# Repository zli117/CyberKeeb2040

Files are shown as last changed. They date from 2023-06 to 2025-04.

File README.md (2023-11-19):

# CyberKeeb 2040
A mechnical keyboard and a cyberdeck. Powered by [PicoMK](https://github.com/zli117/PicoMK) for communication between RP2040 and Pi Zero. Watch the demo on YouTube 👇.

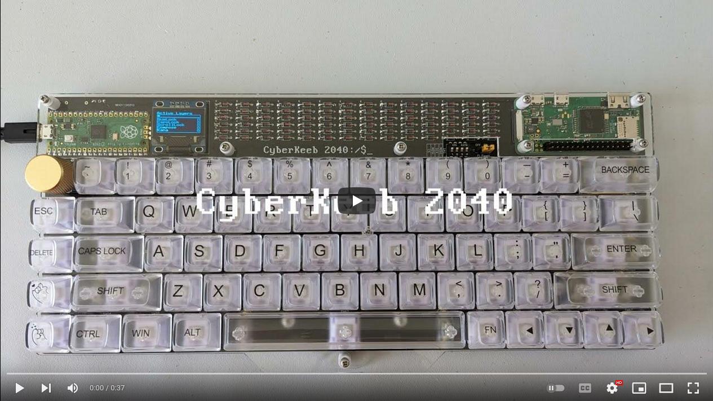
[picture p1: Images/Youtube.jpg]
Watch the demo video (https://youtu.be/GYs4eybdZCU)


# Table of Contents

- [CyberKeeb 2040](#cyberkeeb-2040)
- [Table of Contents](#table-of-contents)
- [Build](#build)
  - [PCB](#pcb)
  - [Frame](#frame)
- [Photos](#photos)
  - [V2](#v2)
  - [V1](#v1)
- [Q\&A](#qa)
- [PCB Library Licenses](#pcb-library-licenses)

# Build

[**V2 parts list and build instructions**](Docs/BuildInstructions_V2.md)

[V1 parts list and build instructions](Docs/BuildInstructions_V1.md)

## PCB
Everything is in [PCB/MainBoard](PCB/MainBoard) dir. Designed with Kicad 7.0. Make sure `Perfect DOS VGA 437 Font` is intalled on Windows, or if you use Arch, install the [ttf-perfectdos](https://aur.archlinux.org/packages/ttf-perfectdos) package. [PCB/MainBoard/Gerber](PCB/MainBoard/Gerber) dir contains the Gerber files for three fab houses: [JLCPCB](PCB/MainBoard/Gerber/JLCPCB/), [PCBWay](PCB/MainBoard/Gerber/PCBWay/), and [OSHPark](PCB/MainBoard/Gerber/OSHPark/). For JLCPCB and PCBWay, **make sure to select the Castellated Holes option** (this will increase the price, but I found it necessary for good castellated holes).

## Frame
The frame has three acrylic plates and is held together with screws and standoffs.

 * [Frame/MainBoard/TopBar.dxf](Frame/MainBoard/TopBar.dxf): 3mm acrlyic
 * [Frame/MainBoard/Plate.dxf](Frame/MainBoard/Plate.dxf): 1.5mm acrlyic
 * [Frame/MainBoard/Bottom.dxf](Frame/MainBoard/Bottom.dxf): 3mm acrlyic

# Photos

## V2

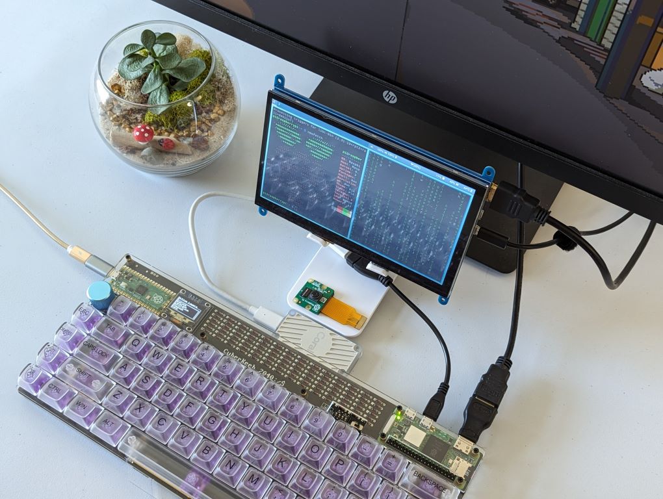
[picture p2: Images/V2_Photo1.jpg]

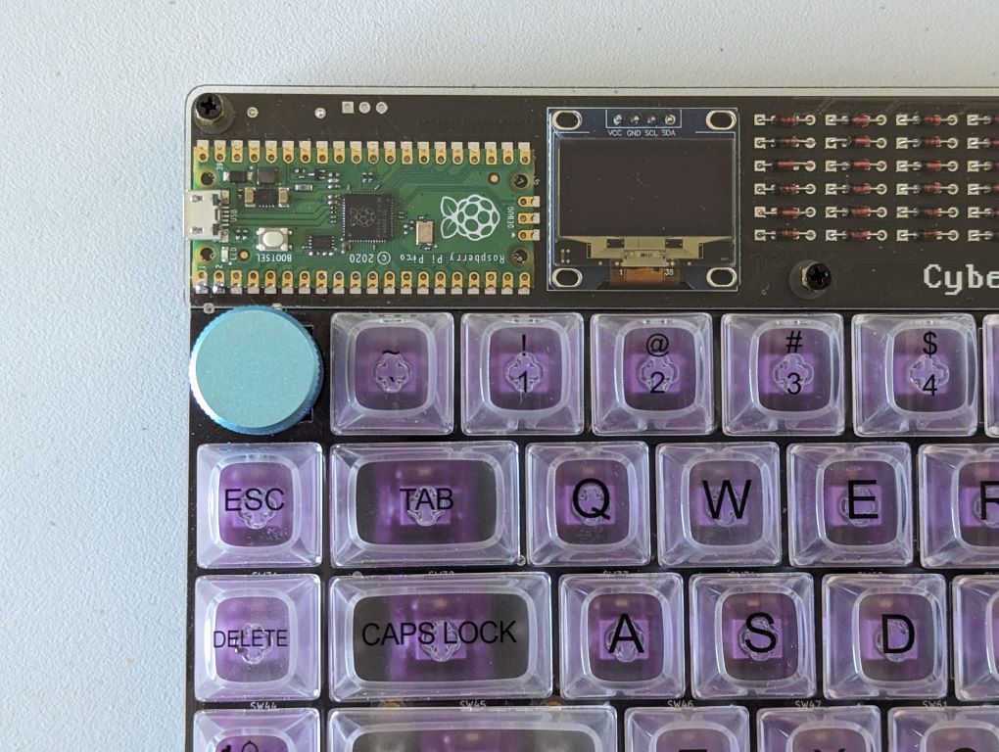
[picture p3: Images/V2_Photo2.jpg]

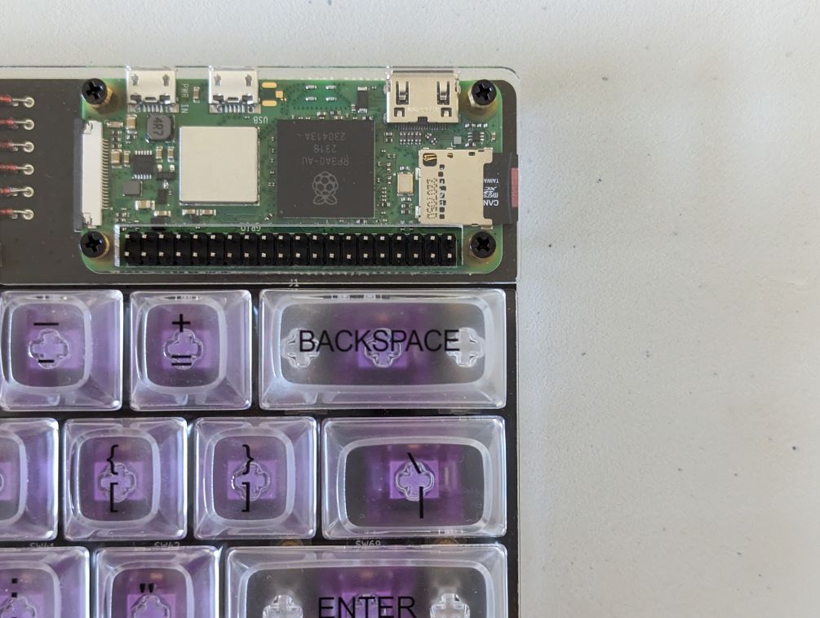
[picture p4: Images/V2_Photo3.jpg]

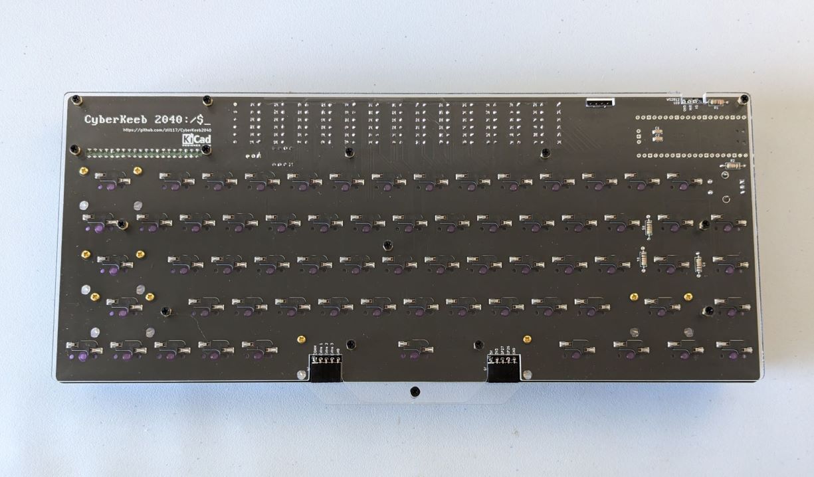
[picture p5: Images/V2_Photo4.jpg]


## V1

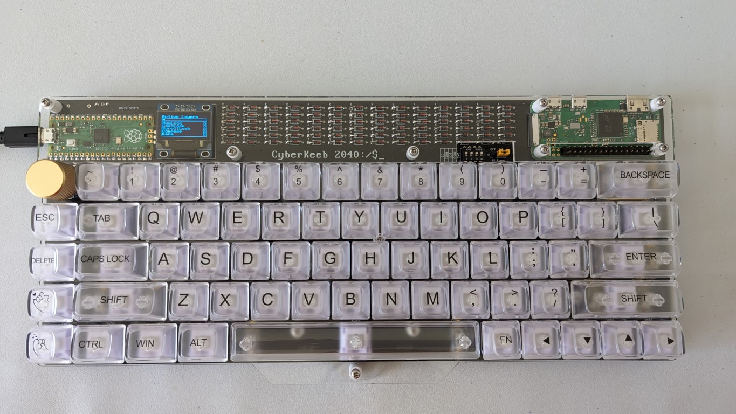
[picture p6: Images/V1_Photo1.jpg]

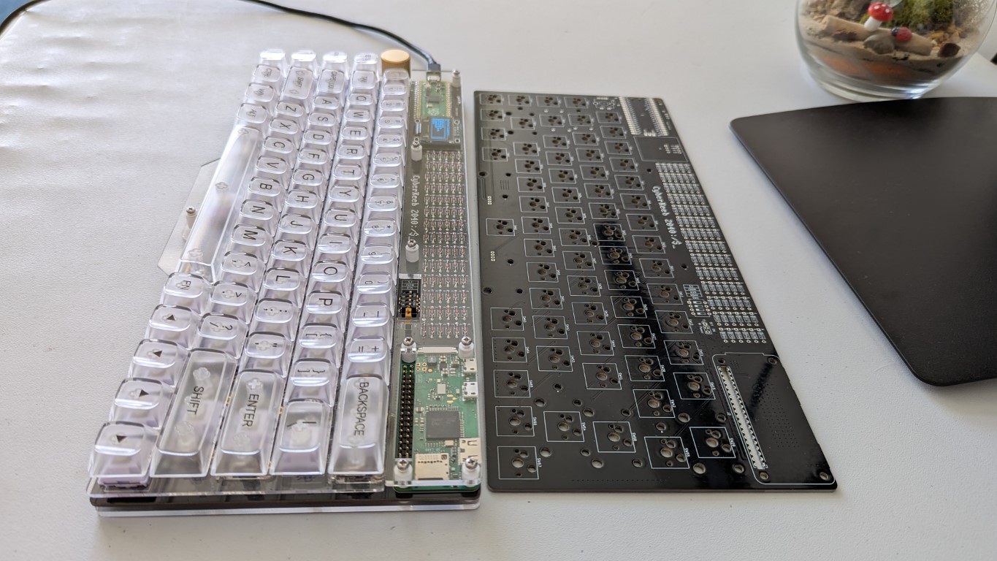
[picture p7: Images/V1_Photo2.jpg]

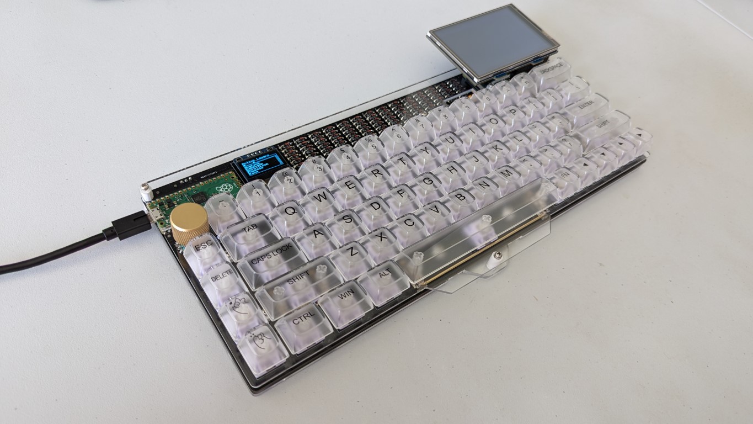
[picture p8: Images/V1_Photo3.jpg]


# Q&A

Special thanks to [icon-oclast](https://github.com/icon-oclast) for [asking](https://github.com/zli117/CyberKeeb2040/issues/2) these great questions.

> What are the dip switches used for? Is there a recommended default setting for these?

The 4 positions are for each line of the SPI connection between the pi pico and pi zero. This allows cutting the connections between pi pico and pi zero without cutting the power connections. I initially designed it for the (paranoid) scenario where I can't kill the pi zero, but doesn't want it to do autotype or receiving the key strokes, but I found such scenario increasing unlikely. So, if you don't want to solder the DIP switches, feel free to just short the corresponding pins.

> Presumably the switch/jumper labeled "pi power" controls pass-through power from the Pico to the Zero?

Yes.

> Is there a minimum USB current needed when powering both boards

I don't have the empirical measurements, but here's the estimate:
Pico: <20mA. Data source: https://mjoldfield.com/atelier/2021/11/pico-power.html
SSD1306: <7mA. Data source: https://hsel.co.uk/2018/12/04/ssd1306-power-consumption/
Pi Zero W: <400mA under stress. Data source: https://www.tomshardware.com/reviews/raspberry-pi-zero-2-w-review
Pi Zero 2 W: <600mA under stress.

So let's say it's 700mA if you want to stress the pi zero. I did run the stressberry on pi zero 2 w, with the display hat, and a wireless mouse receiver. The board is connected to the USB3.0 port and there's no under voltage warning, and no visible heat up on the cable or the connectors. However, due to differences on the motherboards, YMMY. I currently don't have a USB power meter to measure the actual current drawn.

> Is there a maximum safe current to pass-through (when using the optional display hat for example)?

The trace between pico and pi zero has width of 1mm, and length around 300mm. Assuming you're using 1oz copper thickness, it should result in a maximum current of 1.2 A for temperature rise of 10 degree C.

> Is it safe to power the zero independently by setting the pi power switch/jumper to off?

Yes.

> What about the two connectors at the bottom of the board, either 4-pin jst sockets as in the build instructions, or possibly 5-pin headers on some revisions of the pcb, how are they intended to be used?

They are for my future plans :) Essentially, they expose three buttons from the key scan matrix, and pin 26 and 27. Pin 26 and 27 are analog input pins and I2C 1. I'm planning to create a plugin module for the joystick mouse pad similar to the one I have on the Pico-Keyboard, and an I2C expansion board for more modules like a num pad. 

> What cool things can we do if we include the optional 90 degree pin header(s)?

The pin header under the small screen has been removed, because I figured it'll be difficult to use it for anything without creating a giant mess in the firmware. The other header exposes the addressable LEDs. Only WS2812 is supported and tested because it's used in the Pico-Keyboard. However, you might be able to use for other things as it's essentially a GPIO pin with ground and 5V, and a 330 ohm resister on the GPIO pin.

# PCB Library Licenses

 * Pico symbol, footprint from https://github.com/ncarandini/KiCad-RP-Pico under CC-BY-SA 4.0. 3D model for Pico is obtained from Raspberry Pi Foundation.
 * Pi Zero symbol, footprint and 3D model are from [SnapEDA](https://www.snapeda.com/parts/ADA3708/Adafruit%20Industries%20LLC/view-part/) under [CC BY-SA 4.0](https://support.snapeda.com/en/articles/2957814-what-is-the-license-for-symbols-and-footprints)
 * Key switch footprints and 3D models are from https://github.com/kiswitch/kiswitch
 * PJ320A symbol, footprint are from [Keebio-Parts.pretty](https://github.com/keebio/Keebio-Parts.pretty/blob/master/TRRS-PJ-320A.kicad_mod) under MIT License.
 * Other symbols are from KiCad library which is under CC-BY-SA 4.0 license. 

This work is licensed under a
[Creative Commons Attribution-ShareAlike 4.0 International License][cc-by-sa].

[][cc-by-sa]

[cc-by-sa]: http://creativecommons.org/licenses/by-sa/4.0/
[cc-by-sa-image]: https://licensebuttons.net/l/by-sa/4.0/88x31.png
[cc-by-sa-shield]: https://img.shields.io/badge/License-CC%20BY--SA%204.0-lightgrey.svg

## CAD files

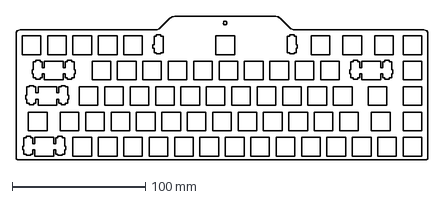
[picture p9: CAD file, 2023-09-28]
Frame/MainBoard/Plate.dxf
308.8 x 107.3 mm

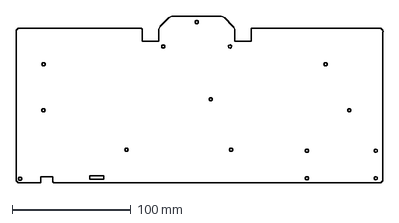
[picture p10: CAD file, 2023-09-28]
Frame/MainBoard/Bottom.dxf
308.8 x 140.3 mm

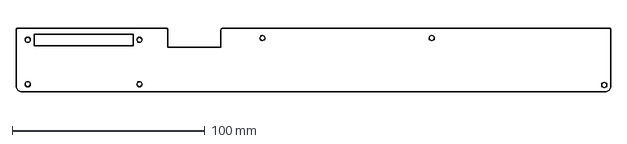
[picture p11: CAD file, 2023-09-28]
Frame/MainBoard/TopBar.dxf
308.8 x 33.0 mm

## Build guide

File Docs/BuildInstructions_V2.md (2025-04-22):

# V2 Build Instructions

## Necessary Parts

| Image | Part Name | Count |
| --- | --- | ----- |
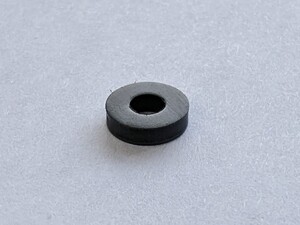
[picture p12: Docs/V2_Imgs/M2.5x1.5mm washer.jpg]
|  | M2.5x1.5mm washer | 3 |
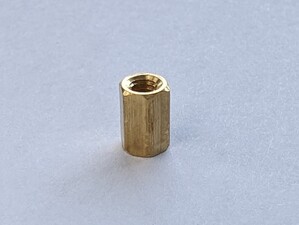
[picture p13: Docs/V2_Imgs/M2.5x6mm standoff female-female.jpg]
|   | M2.5x6mm standoff female-female  | 7 |
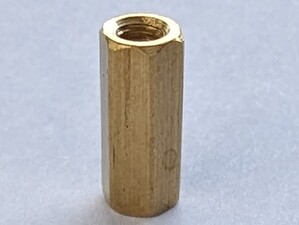
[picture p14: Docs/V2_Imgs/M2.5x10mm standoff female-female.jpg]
|  | M2.5x10mm standoff female-female | 1 |
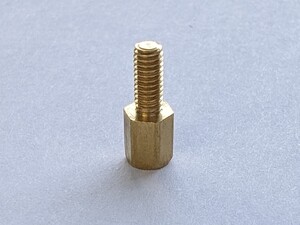
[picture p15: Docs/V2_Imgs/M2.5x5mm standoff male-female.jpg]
|  | M2.5x5mm standoff male-female | 7 |
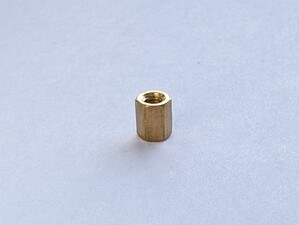
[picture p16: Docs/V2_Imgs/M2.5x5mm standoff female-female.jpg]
|   | M2.5x5mm standoff female-female  | 7 |
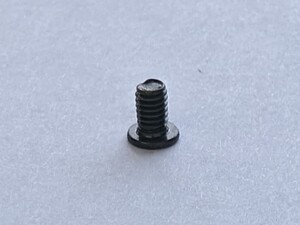
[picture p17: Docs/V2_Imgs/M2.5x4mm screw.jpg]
|  | M2.5x4mm screw | 8 |
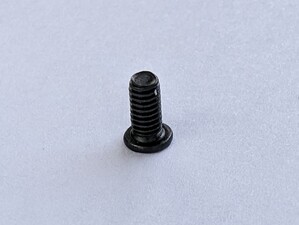
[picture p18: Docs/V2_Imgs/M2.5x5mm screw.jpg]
|  | M2.5x5mm screw | 22 |
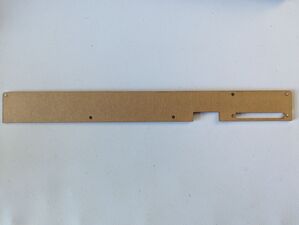
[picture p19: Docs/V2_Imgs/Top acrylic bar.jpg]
|  | Top acrylic bar | 1 |
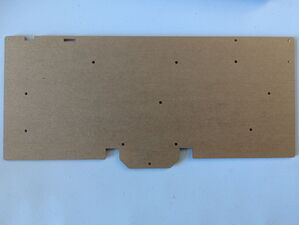
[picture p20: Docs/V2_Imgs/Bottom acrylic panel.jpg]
|  | Bottom acrylic panel | 1 |
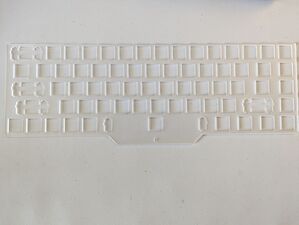
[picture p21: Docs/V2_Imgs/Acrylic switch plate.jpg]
|  | Acrylic switch plate | 1 |
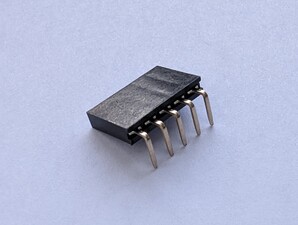
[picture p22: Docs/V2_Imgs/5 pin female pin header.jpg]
|  | 5 pin female pin header | 2 |
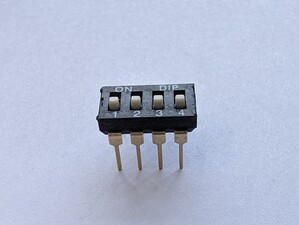
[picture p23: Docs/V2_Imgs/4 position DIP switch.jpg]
|  | 4 position DIP switch | 1 |
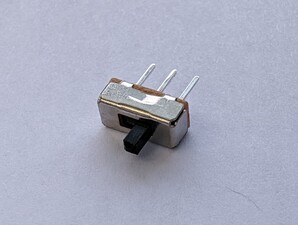
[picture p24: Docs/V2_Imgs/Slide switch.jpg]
|  | Slide switch | 1 |
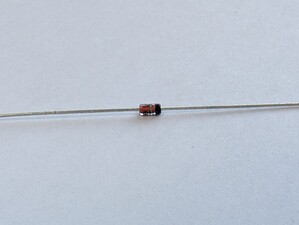
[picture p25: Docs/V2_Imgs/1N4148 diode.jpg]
|  | 1N4148 diode | 84 |
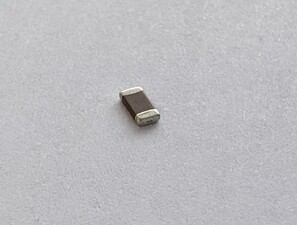
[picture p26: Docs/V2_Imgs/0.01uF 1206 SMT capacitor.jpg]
|  | 0.01uF 1206 SMT capacitor | 2 |
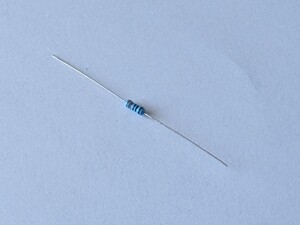
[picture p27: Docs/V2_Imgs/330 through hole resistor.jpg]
|  | 330Ω through hole resistor | 1 |
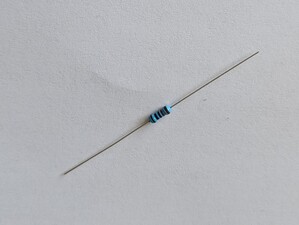
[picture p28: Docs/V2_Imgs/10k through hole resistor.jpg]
|  | 10kΩ through hole resistor | 4 |
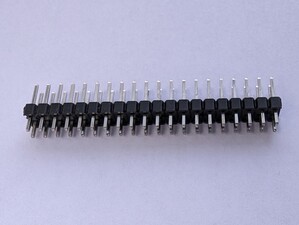
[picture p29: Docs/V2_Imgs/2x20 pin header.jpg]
|  | 2x20 pin header | 1 |
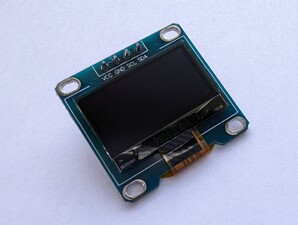
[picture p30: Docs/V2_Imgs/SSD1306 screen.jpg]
|  | SSD1306 screen | 1 |
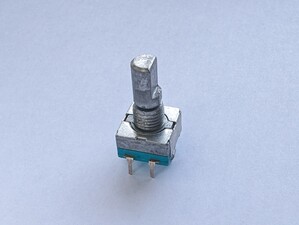
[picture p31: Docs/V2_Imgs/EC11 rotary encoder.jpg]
|  | EC11 rotary encoder | 1 |
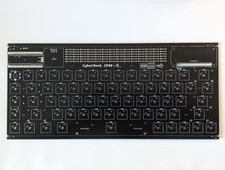
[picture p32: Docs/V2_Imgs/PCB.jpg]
|  | PCB | 1 |
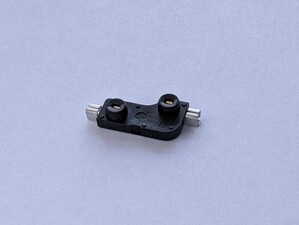
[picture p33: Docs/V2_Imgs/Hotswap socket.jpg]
|  | Hotswap socket | 66 |
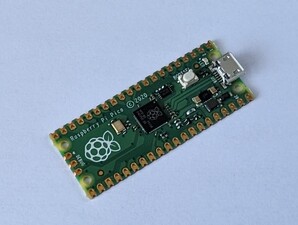
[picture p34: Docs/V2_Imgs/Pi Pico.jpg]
|  | Pi Pico | 1 |
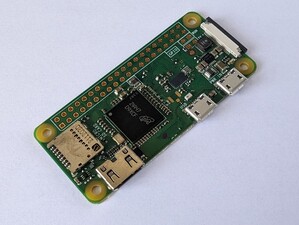
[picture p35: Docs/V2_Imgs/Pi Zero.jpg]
|  | Pi Zero / Zero 2 | 1 |

## You Also Need

- Soldering iron. Conical tip is recommended.
- Solder wire. Thin solder wire with less than 0.03 inch diameter is recommended.
- Tweezer.
- Wire cutter to remove diode pins.
- Tape or hot glue gun.
- Key switches.
- Key caps.
- Stablizers.

## PCB Assembly

### Recommended Assembly Order

1. Diodes
2. Hotswap sockets
3. Resisters
4. Capacitors
5. Pi Pico
6. 5 pin female header + DIP swtich + slide switch
7. Rotary encoder
8. Pi Zero + 2x20 pin header

### Solder Pi Zero 

1. Secure Pi Zero to the PCB using two pairs of male-female and female-female standoffs, as such:

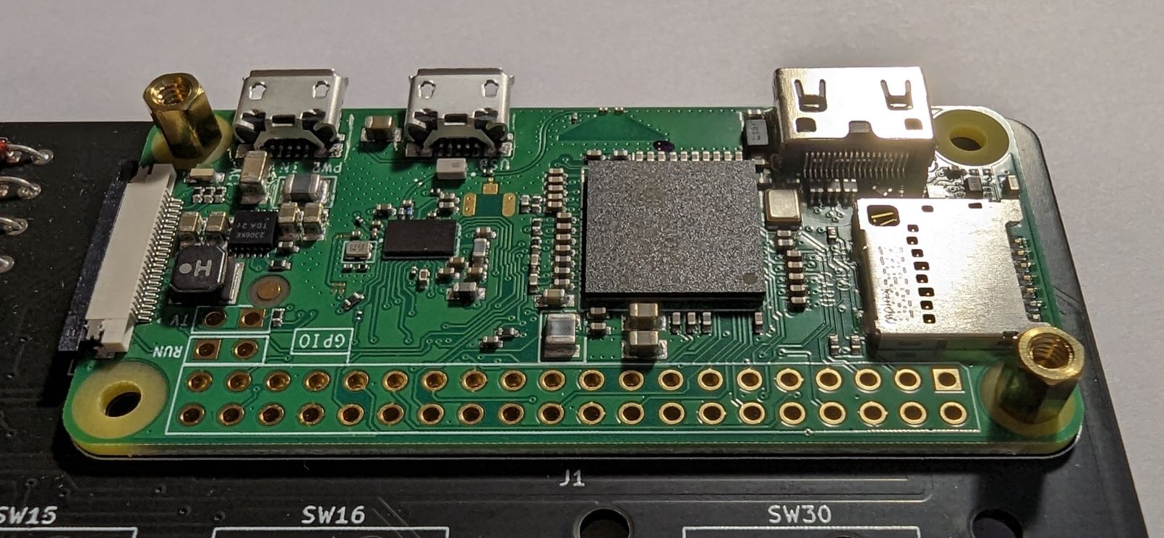
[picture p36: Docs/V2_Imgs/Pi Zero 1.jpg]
Pi Zero Screw Down
   
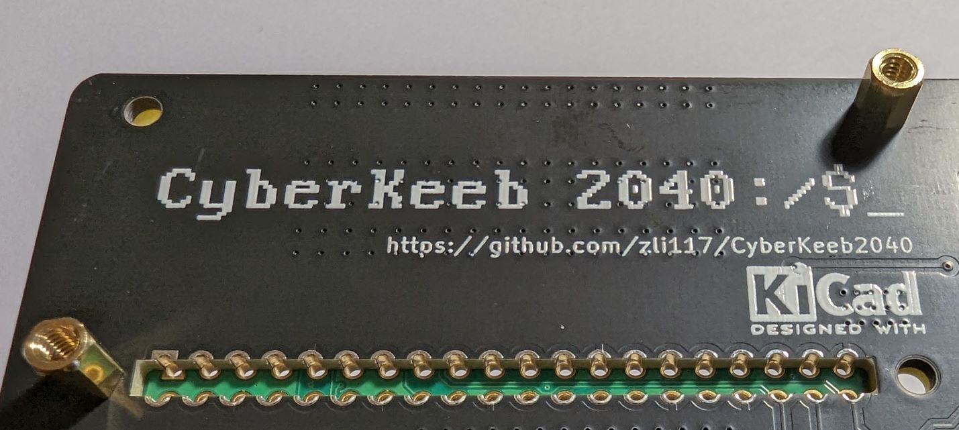
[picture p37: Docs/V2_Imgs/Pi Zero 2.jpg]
Pi Zero Screw Down
   

2. Tape down the pin header

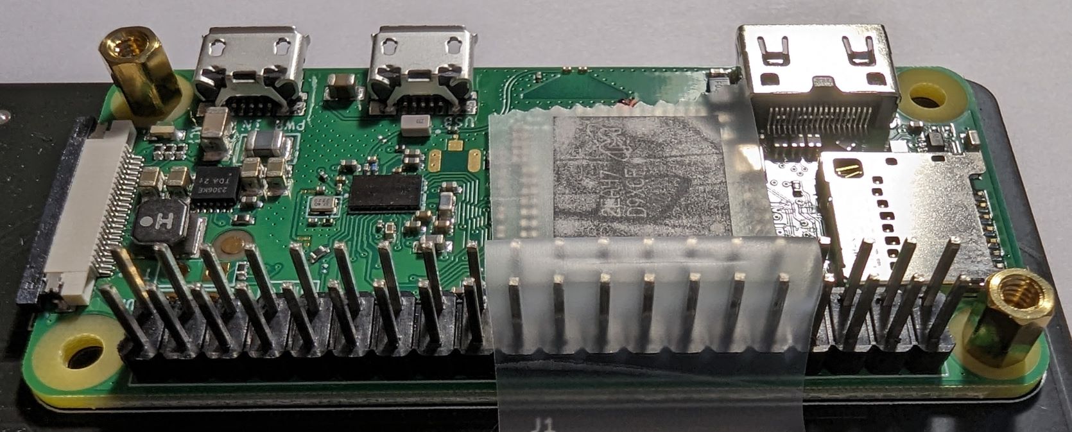
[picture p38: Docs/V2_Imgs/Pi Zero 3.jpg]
Pi Zero Header Tape
   

   You can also use hot glue. Just be careful not to cover the small components on Pi Zero. Remove the tape when soldering the pins it covers. The pins can conduct the heat and melt the tape.

3. Solder the pin with the keyboard PCB and the Pi Zero:

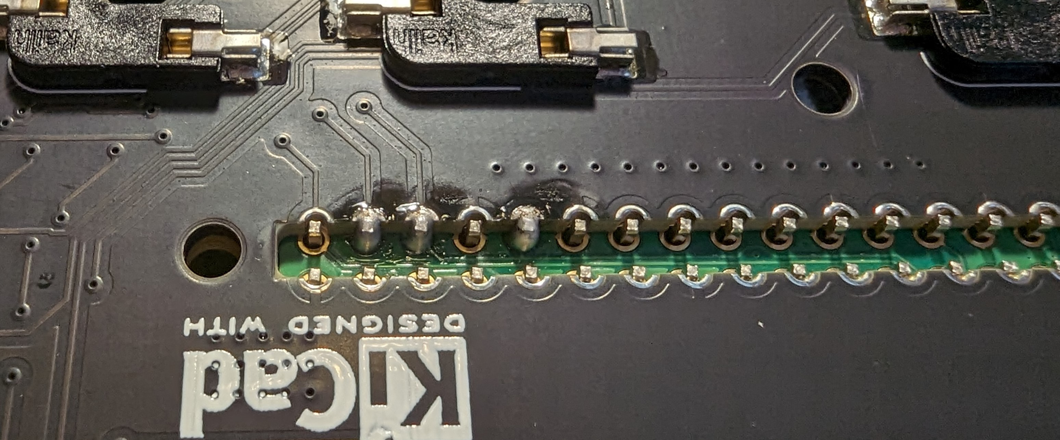
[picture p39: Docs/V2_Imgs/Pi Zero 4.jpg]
Pi Zero Solder
   

   Bring in the soldering iron vertically, and press the tip againt the pin, the keyboard PCB and the Pi Zero PCB. Hold for half a second to a second to heat up the pads. Then feed in the solder wire from the left, touching the pin and the pads:

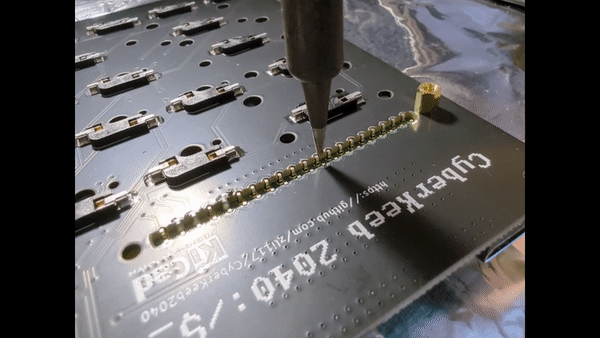
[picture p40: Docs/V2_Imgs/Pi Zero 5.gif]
Pi Zero Solder gif
   

   Tip: use thin solder wire with less than 0.03 inch diameter. 

4. Remove the standoffs. 

### Solder the Diodes

Make sure the cathode band is aligned with the square pad:

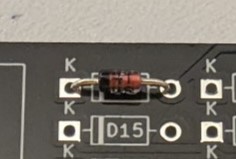
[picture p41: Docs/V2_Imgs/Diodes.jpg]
Diodes


### Solder Hotswap Sockets

1. Tin one of the pads:

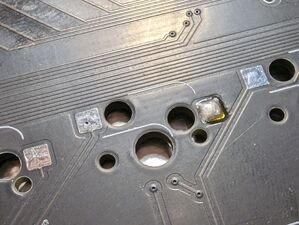
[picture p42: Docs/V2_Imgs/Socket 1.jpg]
Socket 1
   

2. Place the socket, and solder the tinned pin:

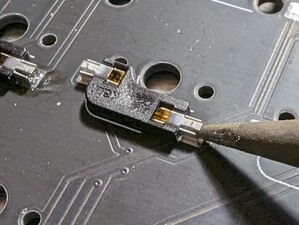
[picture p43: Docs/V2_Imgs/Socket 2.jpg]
Socket 2
   

   Place the tip of the soldering iron as shown and press down. You might also want to use a tweezer to press down on the other pin.

3. Solder the other pin.

### Solder the SMD Capacitors

The process is similar to the hotswap socket. Capacitor doesn't have any polarity.

1. Tin one of the pads.
2. Use the tip of the soldering iron to melt the tin, and slide in the capacitor.
3. Solder the other end.

This [video](https://www.youtube.com/watch?v=_DsCdOaRUPM) is a nice demonstrateion.

## Frame Assembly

### Step 1
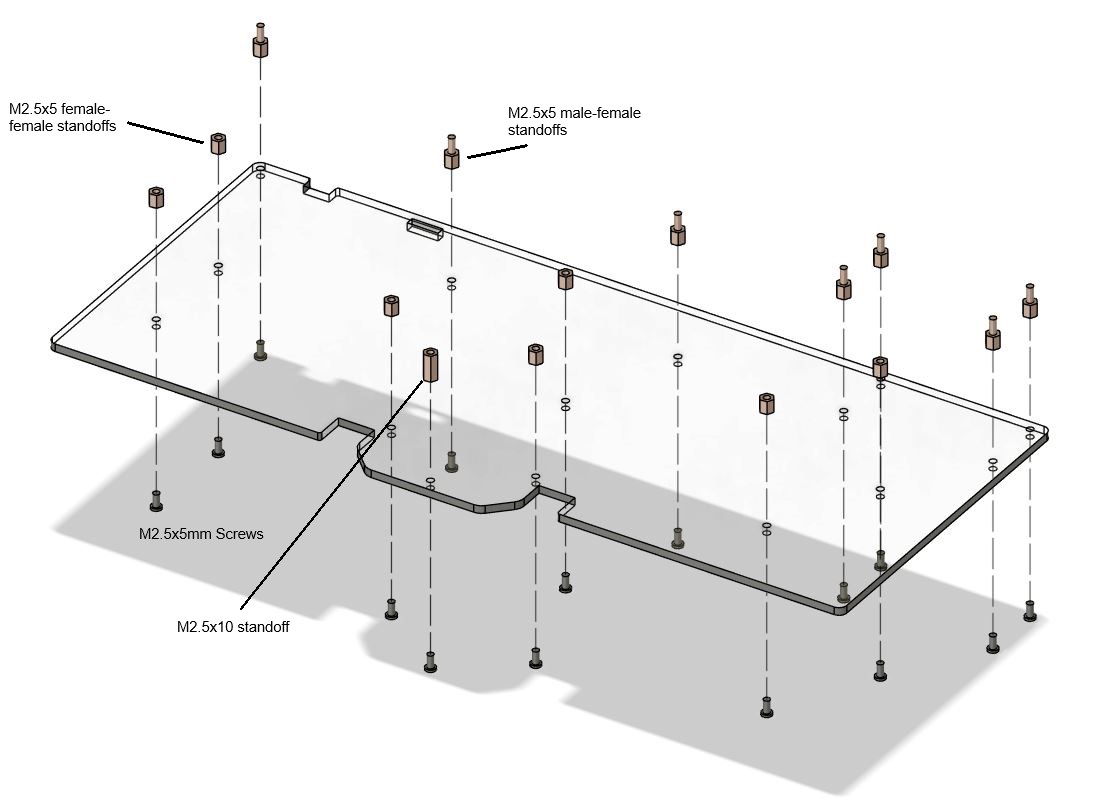
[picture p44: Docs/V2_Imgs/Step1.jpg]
Step 1


Install the standoffs to the bottom panel. All the screws used here are M2.5x5mm. There are 7 M2.5x5 male-female standoffs for the top part of the panel, and 7 M2.5x5 female-female standoffs for the lower part. There's 1 M2.5x10mm standoff at the very bottom.

### Step 2
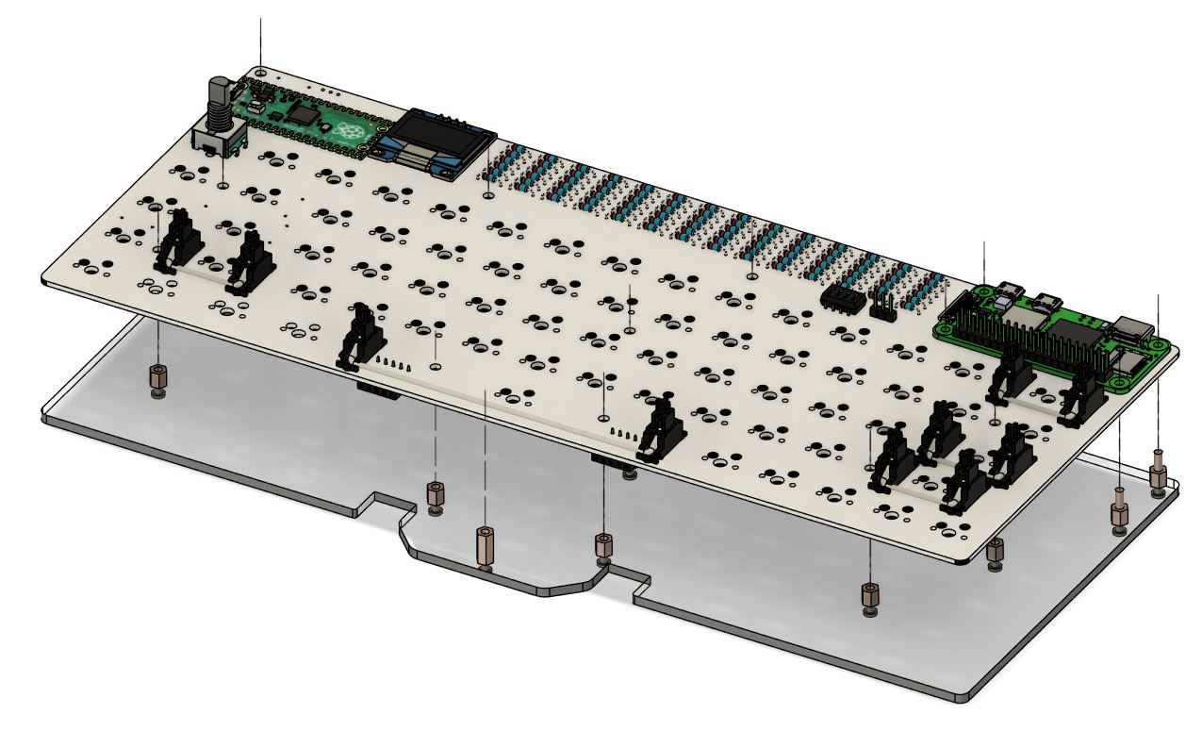
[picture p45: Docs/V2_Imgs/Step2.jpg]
Step 2


Align the PCB to the standoffs.

### Step 3
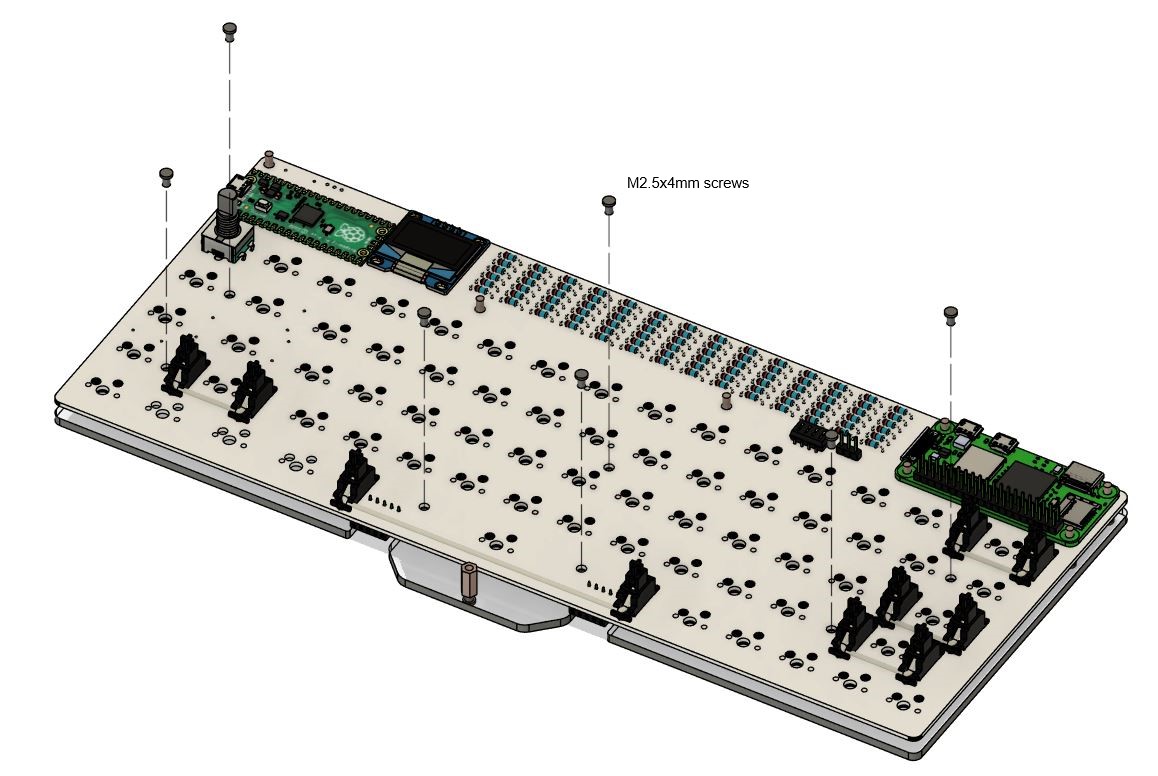
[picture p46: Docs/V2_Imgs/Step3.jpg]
Step 3


Screw down the PCB with 7 M2.5x4mm screws.

### Step 4
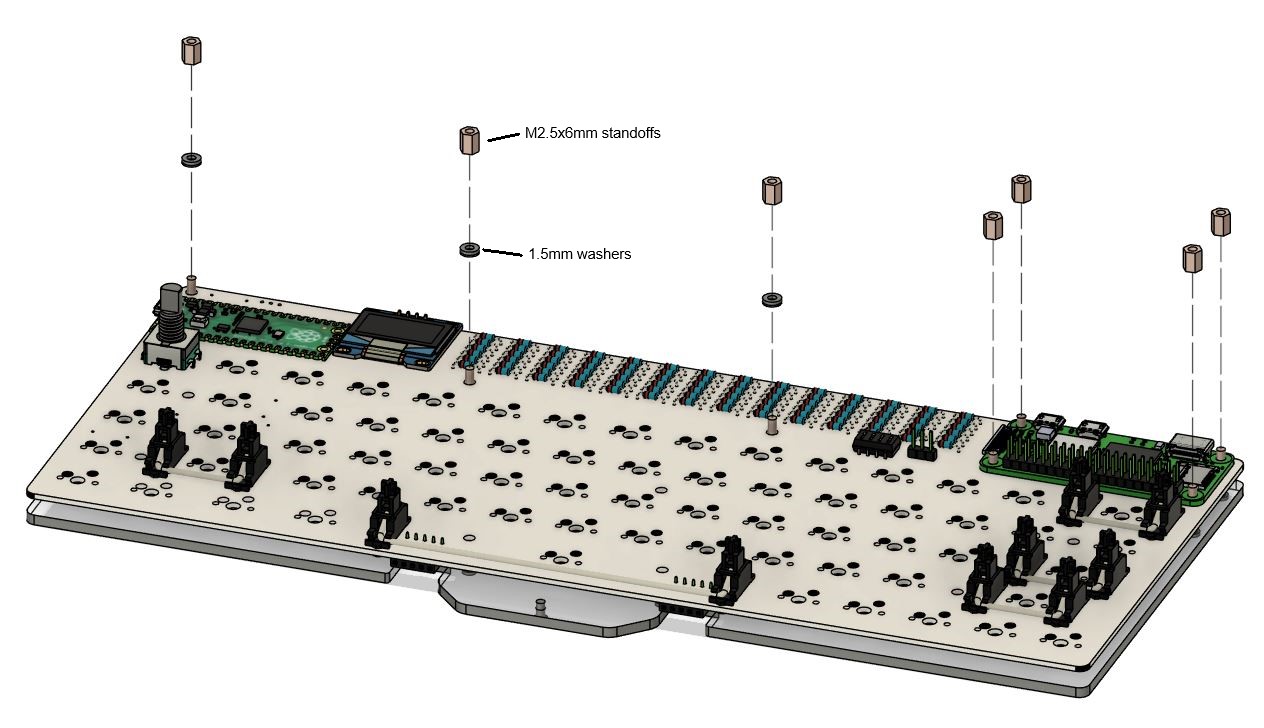
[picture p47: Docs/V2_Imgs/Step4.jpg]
Step 4


Install the top bar standoffs with 7 M2.5x6mm standoffs. For the ones not over the Pi Zero, add a 1.5mm washer.

### Step 5
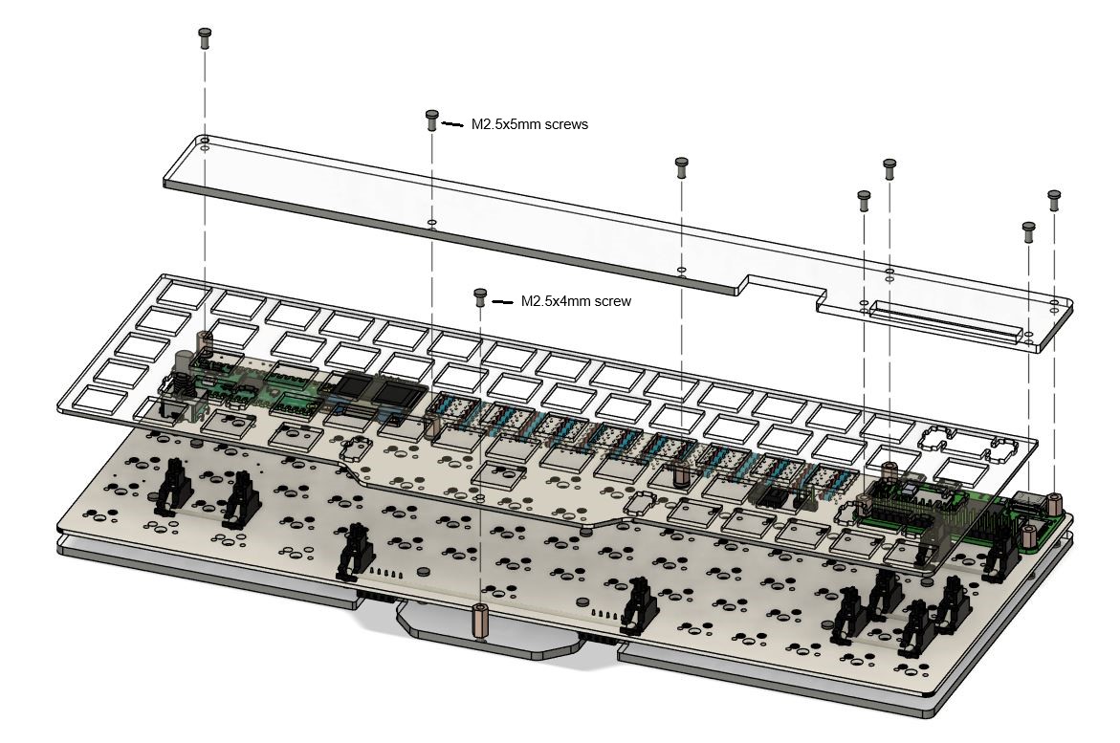
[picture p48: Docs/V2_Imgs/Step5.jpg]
Step 5


Install the top bar and the plate. 

Tip: Add the switches, at least the ones on the edge, to the plate before installing the plate.

## Build Software

### Pi Pico Firmware

Install build dependencies:

Arch Linux:
```bash
pacman -S git cmake arm-none-eabi-gcc arm-none-eabi-newlib
```

For other distros or OS, see https://github.com/zli117/PicoMK#get-the-code

Check out the code:
```bash
git clone https://github.com/zli117/PicoMK.git
cd PicoMK
git submodule update --init && git -C pico-sdk submodule update --init
```

The hardware configuration for this keyboard is defined in `configs/cyberkeeb_2040` dir in `PicoMK`. You can take a look at the [`layout.cc`](https://github.com/zli117/PicoMK/blob/main/configs/cyberkeeb_2040/layout.cc) for the details on the keymap.

Build the firmware:

```bash
mkdir build
cd build
cmake -DBOARD_CONFIG=cyberkeeb_2040 ..
make -j 4
```

If successful, you can find the `firmware.uf2` file in the build dir. Now, hold down the flash button on the Pico and plug it in. It will show up as a USB drive. Just copy the `firmware.uf2` file to the drive.

### Pi Zero Kernel Module

To send the keycodes to the Pi Zero, a kernel module is needed on the Pi Zero side, as it uses a custom [protocol](https://github.com/zli117/PicoMK/blob/main/docs/ibp.md) defined over SPI.

For this you'll need an external keyboard. 

1. Install kernel headers: `sudo apt install raspberrypi-kernel-headers`
2. Checkout PicoMK `git clone https://github.com/zli117/PicoMK.git`.
3. Build the driver and device tree overlay:
```bash
cd PicoMK/linux
make -j
make device_tree
```
4. Install the driver:
```bash
sudo -E make install
sudo depmod -a
```
5. Copy over the device tree overlay: `sudo cp spi1-picomk.dtbo /boot/overlays`.
6. Add this line to the `/boot/config.txt`. Make sure SPI1 is not enabled.
```
dtoverlay=spi1-picomk
```
7. Add this line to the `/etc/modules` file:
```
spi_picomk
```

If you update the Raspberry Pi OS, especially with kernel updates, you'll need to rebuild the kernel module (rerun step 4).

If you want to use the 3.5 inch GPIO TFT screen, and you're on Pi Zero, install the driver from https://github.com/juj/fbcp-ili9341. If you're on Pi Zero 2, install the driver from https://github.com/goodtft/LCD-show.

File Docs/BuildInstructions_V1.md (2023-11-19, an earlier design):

# V1 Build Instructions

## BOM
| Component | Count |
| --- | --- |
| Pi Pico  | 1 |
| Pi Zero W or Pi Zero 2 W  | 1 |
| Pi Zero 2x20 Header Pins  | 1 |
| SD Card  | 1 |
| JMD0.96C OLED Display | 1 |
| 4 Position DIP Switch | 1 |
| 0.1" 3 Pin Header + Jumper / 0.1" Pitch SPDT Slide Switch | 1 |
| Hotswap Socket | 66 |
| Keyboard Switch (Hippo Linear) | 66 |
| Keycaps (Redragon Crystal Keycap) | 66 |
| EC11 Rotary Encoder | 1 |
| Encoder Knob (Glorious) | 1 |
| 1N4148 Diode | 84 |
| M2.6 x 10mm Self Tapping Screws | 8 |
| M2.6 x 16mm Self Tapping Screws | 7 |
| 3mm Acrylic Sheet | 2 |
| 1.5mm Acrylic Sheet | 1 |
| 3D Printed Rivet + Spacers | 15 |
| JST-PH 2.0mm 4 Pin Female Connector | 2 |
| Stablizer Set | 1 |
| 330Ω THT Resister | 1 |
| 10kΩ THT Resister | 4 |
| 1206 0.01 µF Capacitor | 2 |
| (Optional) 3.5 inch TFT Display HAT | 1 |
| (Optional) 0.1" 3 Pin 90° Header | 1 |
| (Optional) 0.1" 4 Pin 90° Header | 1 |

## PCB
Everything is in [PCB/MainBoard](PCB/MainBoard) dir. Designed with Kicad 7.0. Make sure `Perfect DOS VGA 437 Font` is intalled on Windows, or if you use Arch, install the [ttf-perfectdos](https://aur.archlinux.org/packages/ttf-perfectdos) package. [PCB/MainBoard/Gerber](PCB/MainBoard/Gerber) dir contains the Gerber files for three fab houses: [JLCPCB](PCB/MainBoard/Gerber/JLCPCB/), [PCBWay](PCB/MainBoard/Gerber/PCBWay/), and [OSHPark](PCB/MainBoard/Gerber/OSHPark/). For JLCPCB and PCBWay, **make sure to select the Castellated Holes option** (this will increase the price, but it's better to be safe on the quality side).

## Case
The case comprises three acrylic plates and various 3D printed rivets. The original Fusion 360 archive is `Frame/MainBoard/CyberKeep 2040 V2 v34.f3d`. The spacer heights are parameterized.

 * [Frame/MainBoard/TopBar.dxf](Frame/MainBoard/TopBar.dxf): 3mm acrlyic
 * [Frame/MainBoard/Plate.dxf](Frame/MainBoard/Plate.dxf): 1.5mm acrlyic
 * [Frame/MainBoard/Bottom.dxf](Frame/MainBoard/Bottom.dxf): 3mm acrlyic

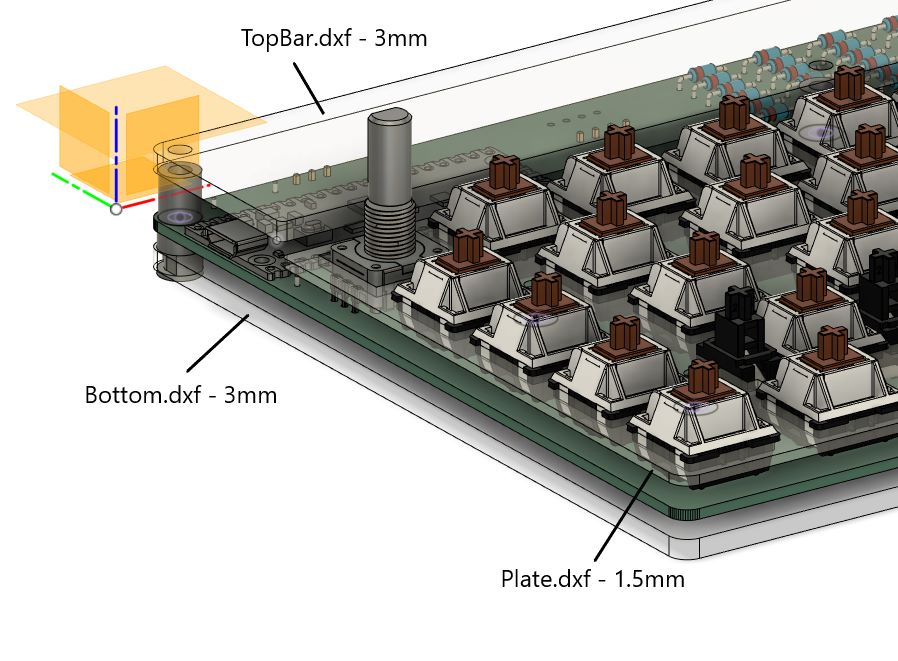
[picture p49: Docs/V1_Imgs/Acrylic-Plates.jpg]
Plates Image


The case is held together with 3D printed rivets and spacers.

### Step 1: Assemble the rivets and bottom spacers
Place the rivets through the holes on the bottom place. Then fit the spacer rings.
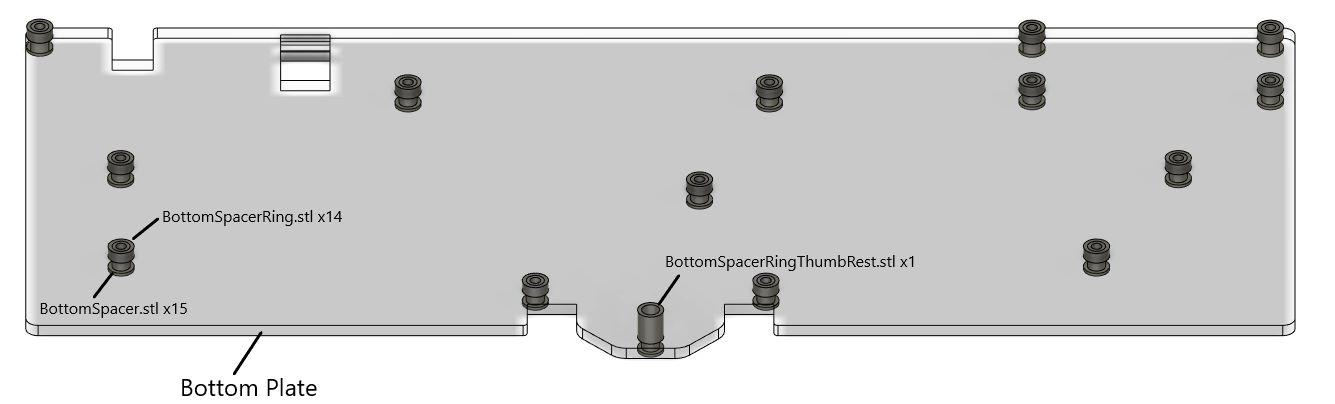
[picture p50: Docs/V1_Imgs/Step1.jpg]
Step 1


### Step 2: Place the top spacers
Place the PCB on top of the bottom spacers. Then place the top spacers as shown.
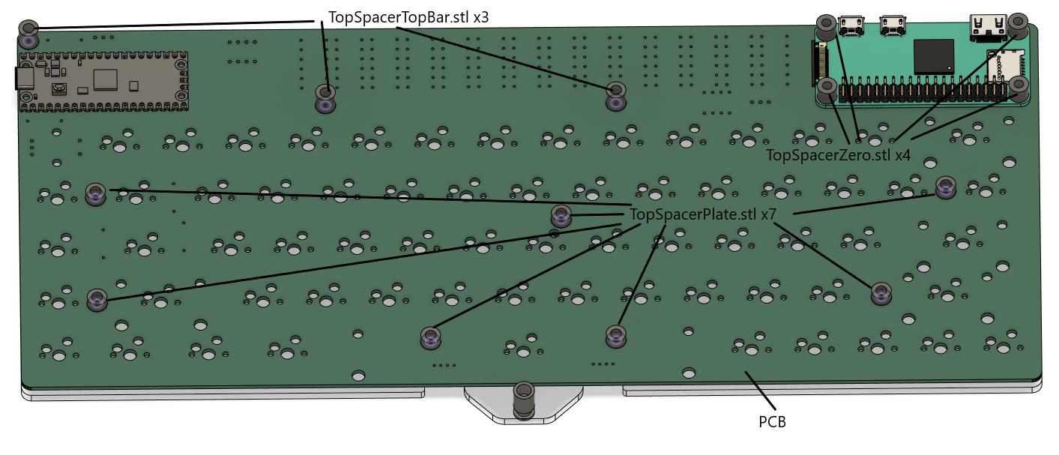
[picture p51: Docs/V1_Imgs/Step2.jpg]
Step 2


### Step 3: Secure the top plates with screws
Place the top bar acrylic plate and the switch plate on top of the top spacers. Then secure the whole assembly with screws. Use M2.6x16mm screws for the top plate, and M2.6x10mm screws for the switch plate.
Step 3

## Soldering

### Pi Zero
Soldering of Pi Zero is the trickiest. You need to solder the pins simultaneously to the keyboard PCB and the Pi Zero, via the castellated hole on the PCB. 

Zero_Bottom

This is viewed from the bottom, at the castellated hole. The green PCB is Pi Zero. Solder joint should form between the copper on the keyboard PCB, the plates on Pi Zero PCB and the pin. To make things easier, it's recommended to tape down the Pi Zero and headers:

Zero_Top

It's also recommended to solder all the pins for structural strength.

### Diodes
Align the dark side of the diode with the square pad.

Diodes

### JST Connector
Install the JST connectors on the back of the PCB. You can either solder on the back side or on the front. If on the front, tape down the connectors first.

JST

### JMD0.96C OLED Display (Marked as J4 on the front of the PCB)

If J3 is installed on the back of the PCB, place a tape on the back of the display to avoid shorting.

## Software

Keyboard firmware: https://github.com/zli117/PicoMK/tree/main/configs/cyberkeeb_2040. Follow PicoMK's [instruction](https://github.com/zli117/PicoMK/tree/main#build-a-firmware) to build the firmware and upload it to Pico microcontroller.

Linux driver for accepting key strokes from SPI: (You'll need an external screen and an external keyboard for this setup)
 1. Install kernel headers: `sudo apt install raspberrypi-kernel-headers` 
 2. Checkout PicoMK: `git clone https://github.com/zli117/PicoMK.git`
 3. Build the driver and device tree overlay:
    ```bash
    cd PicoMK/linux
    make -j
    make device_tree
    ```
 4. Install the driver: 
    ```bash
    sudo -E make install
    sudo depmod -a
    ```
 5. Copy over the device tree overlay: `sudo cp spi1-picomk.dtbo /boot/overlays`
 6. Add this line to the `config.txt`. Make sure SPI1 is not enabled. 
    ```
    dtoverlay=spi1-picomk
    ``` 
 7. Add this line to the `/etc/modules` file:
    ```
    spi_picomk
    ```

 If you're using the 3.5 inch TFT screen, you can install the driver from https://github.com/juj/fbcp-ili9341.

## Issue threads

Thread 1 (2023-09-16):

Missing Gerber directory

icon-oclast, 2023-09-16:
The Build Instructions in the ReadMe file mention a directory PCB/MainBoard/Gerber which doesn't exist in the repo HEAD.
Clicking the link gives a 404 response.

It appears the Gerber directory did exist up until the cleanup commit on Sep 6th.
It would be useful to have these restored, or alternately If removing these from the repo entirely was the intent, then the ReadMe should be updated.

zli117, 2023-09-16:
Thanks for the reminder! I removed the Gerber files as I'm doing some final tweaks on the PCB design. Will update once the new design is verified. I'm currently waiting for the new boards to arrive.

icon-oclast, 2023-10-08:
I see the latest update once again has Gerber files.
Thank you!

Closed 2023-10-08.

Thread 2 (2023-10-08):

operating details

icon-oclast, 2023-10-08:
This keyboard has some very unique features not found in any other keyboard.
Unfortunately there appears to be little information regarding these beyond the build instructions.  Some of these may benefit from some additional detail.  For example:
  * What are the dip switches used for?  Is there a recommended default setting for these?
  * Presumably the switch/jumper labeled "pi power" controls pass-through power from the Pico to the Zero?  Is there a minimum USB  current needed when powering both boards?  Is there a maximum safe current to pass-through (when using the optional display hat for example)?  Is it safe to power the zero independently by setting the pi power switch/jumper to off?
  * What about the two connectors at the bottom of the board, either 4-pin jst sockets as in the build instructions, or possibly 5-pin headers on some revisions of the pcb, how are they intended to be used?
  * What cool things can we do if we include the optional 90 degree pin header(s)?

Any details or suggestions are greatly appreciated!

zli117, 2023-10-08:
Hello icon-oclast, thanks for the questions. Here are the responses:

> What are the dip switches used for? Is there a recommended default setting for these?

The 4 positions are for each line of the SPI connection between the pi pico and pi zero. This allows cutting the connections between pi pico and pi zero without cutting the power connections. I initially designed it for the (paranoid) scenario where I can't kill the pi zero, but doesn't want it to do autotype or receiving the key strokes, but I found such scenario increasing unlikely. So, if you don't want to solder the DIP switches, feel free to just short the corresponding pins

> Presumably the switch/jumper labeled "pi power" controls pass-through power from the Pico to the Zero?

Yes

>  Is there a minimum USB current needed when powering both boards

I don't have the empirical measurements, but here's the estimate:
Pico: <20mA. Data source: https://mjoldfield.com/atelier/2021/11/pico-power.html
SSD1306: <7mA. Data source: https://hsel.co.uk/2018/12/04/ssd1306-power-consumption/
Pi Zero W: <400mA under stress. Data source: https://www.tomshardware.com/reviews/raspberry-pi-zero-2-w-review
Pi Zero 2 W: <600mA under stress.

So let's say it's 700mA if you want to stress the pi zero. I did run the stressberry on pi zero 2 w, with the display hat, and a wireless mouse receiver. The board is connected to the USB3.0 port and there's no under voltage warning, and no visible heat up on the cable or the connectors. However, due to differences on the motherboards, YMMY. I currently don't have a USB power meter to measure the actual current drawn.

> Is there a maximum safe current to pass-through (when using the optional display hat for example)?

The trace between pico and pi zero has width of 1mm, and length around 300mm. Assuming you're using 1oz copper thickness, it should result in a maximum current of 1.2 A for temperature rise of 10 degree C.

> Is it safe to power the zero independently by setting the pi power switch/jumper to off?

Yes.

> What about the two connectors at the bottom of the board, either 4-pin jst sockets as in the build instructions, or possibly 5-pin headers on some revisions of the pcb, how are they intended to be used?

They are for my future plans :) Essentially, they expose three buttons from the key scan matrix, and pin 26 and 27. Pin 26 and 27 are analog input pins as well as I2C 1. I'm planning to create a plugin module for the joystick mouse pad similar to the one I have on the Pico-Keyboard, and an I2C expansion board for more modules like a num pad. However, I'm currently busy preparing the kits as requested by many folks on reddit so it'll have to wait

> What cool things can we do if we include the optional 90 degree pin header(s)?

The pin header under the small screen has been removed, because I figured it'll be difficult to use it for anything without creating a giant mess in the firmware. The other header exposes the addressable LEDs. Only WS2812 is supported and tested because it's used in the Pico-Keyboard. However, you might be able to use for other things as it's essentially a GPIO pin with ground and 5V, and a 330 ohm resister on the GPIO pin.

icon-oclast, 2023-10-09:
This is great information, Thank you!
I hope this info will make it into a future revision of the readme or other documentation file (or at the very least a github project wiki page or whatever).

I do really like the idea of having a data connection cutoff switch(es) separate from the board pass-through power. I'm sure there are a few use cases where that might come in handy.

I'm looking forward to whatever expansion modules you come up with. There's a lot of cool potential here.

zli117, 2023-11-19:
Thank you for the great questions! I've added them to the README, as you suggested. Close the issue for now.

Closed 2023-11-19.

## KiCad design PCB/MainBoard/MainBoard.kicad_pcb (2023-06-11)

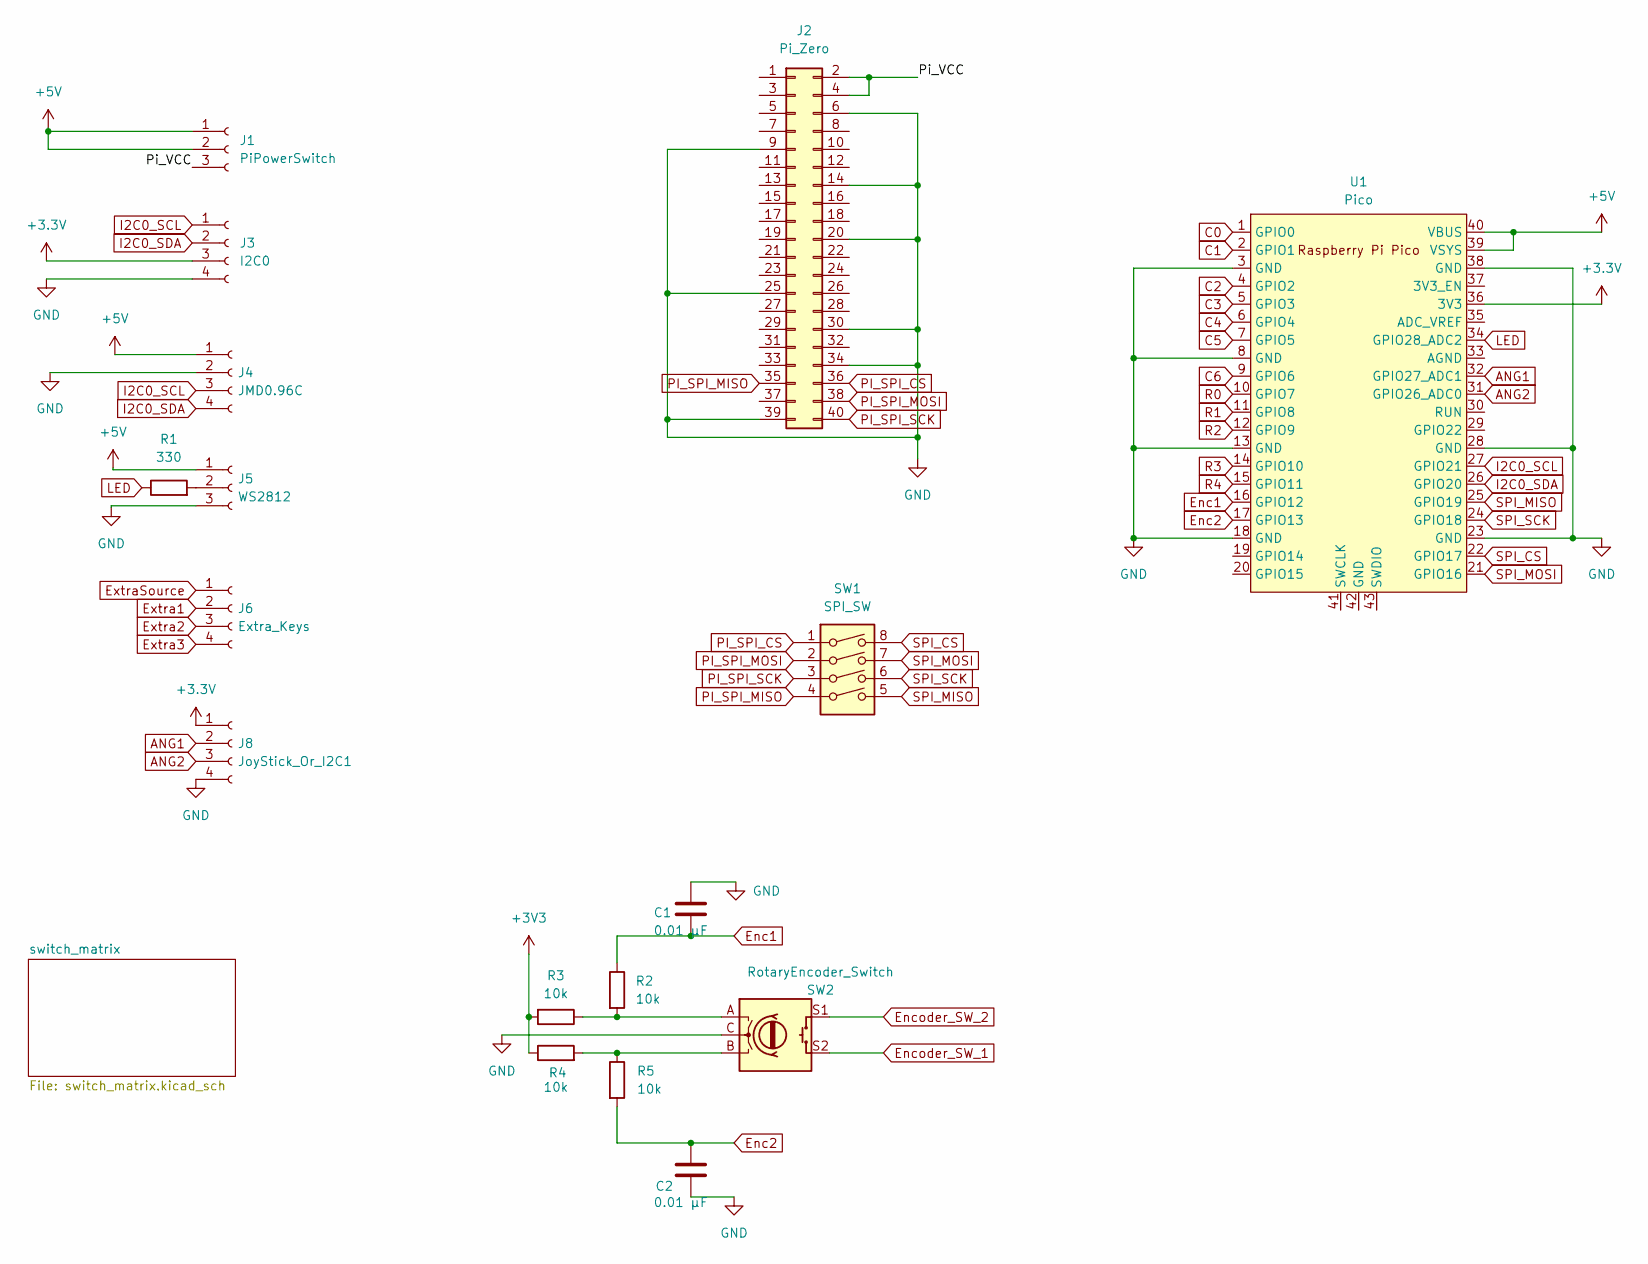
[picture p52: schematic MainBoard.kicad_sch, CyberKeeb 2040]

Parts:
C1, C2: 0.01 μF; C_1206_3216Metric_Pad1.33x1.80mm_HandSolder
J1: PiPowerSwitch; PinHeader_1x03_P2.54mm_Vertical
J2: Pi_Zero; Raspberry_Pi_Zero_Socketed_THT_MountingHoles_Castellated
J3: I2C0; PinHeader_1x04_P2.54mm_Horizontal
J4: JMD0.96C
J5: WS2812; PinHeader_1x03_P2.54mm_Horizontal
J6: Extra_Keys; JST_PH_S4B-PH-K_1x04_P2.00mm_Horizontal
J8: JoyStick_Or_I2C1; JST_PH_S4B-PH-K_1x04_P2.00mm_Horizontal
R1: 330; R_Axial_DIN0207_L6.3mm_D2.5mm_P10.16mm_Horizontal
R2, R3, R4, R5: 10k; R_Axial_DIN0207_L6.3mm_D2.5mm_P10.16mm_Horizontal
SW1: SPI_SW; SW_DIP_SPSTx04_Slide_6.7x11.72mm_W7.62mm_P2.54mm_LowProfile
SW2: RotaryEncoder_Switch; RotaryEncoder_Alps_EC11E-Switch_Vertical_H20mm_CircularMoun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
U1: Pico; RPi_Pico_SMD_TH

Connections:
+5V: J1.1, J1.2, J4.1, J5.1, U1.39 (VSYS), U1.40 (VBUS)
/Pi_VCC: J1.3, J2.2, J2.4
ANG1: J8.2, U1.32 (GPIO27_ADC1)
ANG2: J8.3, U1.31 (GPIO26_ADC0)
C0: U1.1 (GPIO0); also elsewhere on the board
C1: U1.2 (GPIO1); also elsewhere on the board
C2: U1.4 (GPIO2); also elsewhere on the board
C3: U1.5 (GPIO3); also elsewhere on the board
C4: U1.6 (GPIO4); also elsewhere on the board
C5: U1.7 (GPIO5); also elsewhere on the board
C6: U1.9 (GPIO6); also elsewhere on the board
Enc1: C1.2, R2.1, U1.16 (GPIO12)
Enc2: C2.1, R5.2, U1.17 (GPIO13)
Encoder_SW_1: SW2.S2; also elsewhere on the board
Encoder_SW_2: SW2.S1; also elsewhere on the board
Extra1: J6.2; also elsewhere on the board
Extra2: J6.3; also elsewhere on the board
Extra3: J6.4; also elsewhere on the board
ExtraSource: J6.1; also elsewhere on the board
GND: C1.1, C2.2, J2.6, J2.9, J2.14, J2.20, J2.25, J2.30, J2.34, J2.39, J3.4, J4.2, J5.3, J8.4, SW2.C, U1.3 (GND), U1.8 (GND), U1.13 (GND), U1.18 (GND), U1.23 (GND), U1.28 (GND), U1.38 (GND)
I2C0_SCL: J3.1, J4.3, U1.27 (GPIO21)
I2C0_SDA: J3.2, J4.4, U1.26 (GPIO20)
LED: R1.1, U1.34 (GPIO28_ADC2)
unnamed: J5.2, R1.2
unnamed: R2.2, R3.1, SW2.A
unnamed: R4.2, R5.1, SW2.B
PI_SPI_CS: J2.36, SW1.1
PI_SPI_MISO: J2.35, SW1.4
PI_SPI_MOSI: J2.38, SW1.2
PI_SPI_SCK: J2.40, SW1.3
R0: U1.10 (GPIO7); also elsewhere on the board
R1: U1.11 (GPIO8); also elsewhere on the board
R2: U1.12 (GPIO9); also elsewhere on the board
R3: U1.14 (GPIO10); also elsewhere on the board
R4: U1.15 (GPIO11); also elsewhere on the board
SPI_CS: SW1.8, U1.22 (GPIO17)
SPI_MISO: SW1.5, U1.25 (GPIO19)
SPI_MOSI: SW1.7, U1.21 (GPIO16)
SPI_SCK: SW1.6, U1.24 (GPIO18)

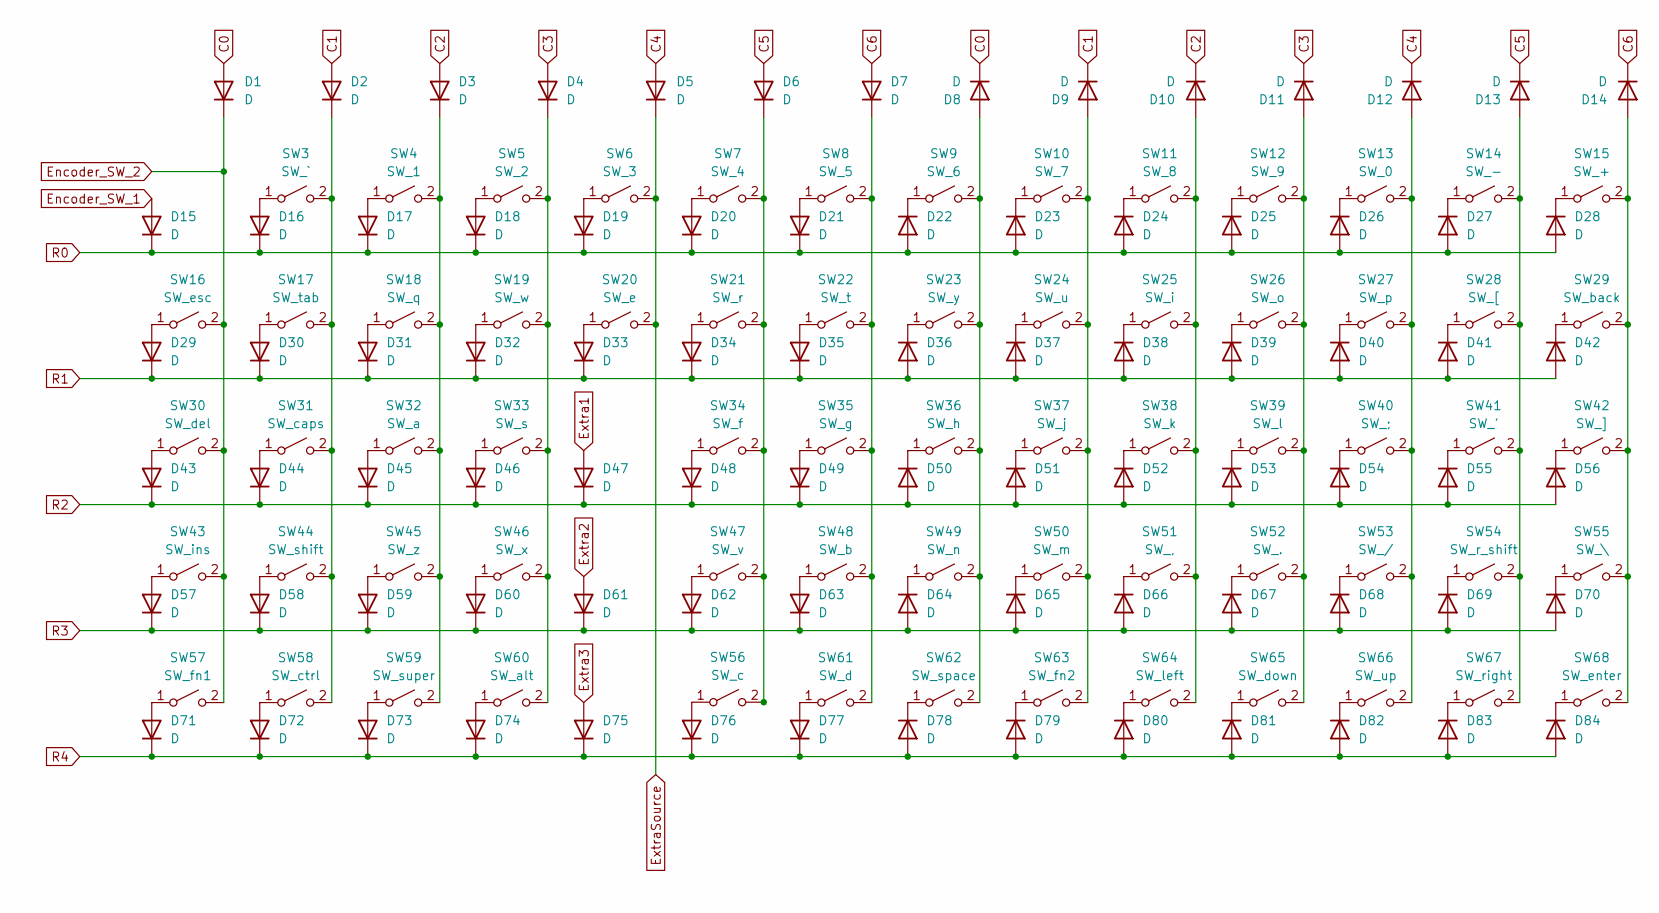
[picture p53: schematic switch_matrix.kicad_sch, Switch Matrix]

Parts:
D1, D2, D3, D4, D5, D6, D7, D8, D9, D10, D11, D12, D13, D14, D15, D16, D17, D18, D19, D20, D21, D22, D23, D24, D25, D26, D27, D28, D29, D30, D31, D32, D33, D34, D35, D36, D37, D38, D39, D40, D41, D42, D43, D44, D45, D46, D47, D48, D49, D50, D51, D52, D53, D54, D55, D56, D57, D58, D59, D60, D61, D62, D63, D64, D65, D66, D67, D68, D69, D70, D71, D72, D73, D74, D75, D76, D77, D78, D79, D80, D81, D82, D83, D84: D; D_DO-35_SOD27_P7.62mm_Horizontal
SW3: SW_`; SW_Hotswap_Kailh_MX_1.00u
SW4: SW_1; SW_Hotswap_Kailh_MX_1.00u
SW5: SW_2; SW_Hotswap_Kailh_MX_1.00u
SW6: SW_3; SW_Hotswap_Kailh_MX_1.00u
SW7: SW_4; SW_Hotswap_Kailh_MX_1.00u
SW8: SW_5; SW_Hotswap_Kailh_MX_1.00u
SW9: SW_6; SW_Hotswap_Kailh_MX_1.00u
SW10: SW_7; SW_Hotswap_Kailh_MX_1.00u
SW11: SW_8; SW_Hotswap_Kailh_MX_1.00u
SW12: SW_9; SW_Hotswap_Kailh_MX_1.00u
SW13: SW_0; SW_Hotswap_Kailh_MX_1.00u
SW14: SW_-; SW_Hotswap_Kailh_MX_1.00u
SW15: SW_+; SW_Hotswap_Kailh_MX_1.00u
SW16: SW_esc; SW_Hotswap_Kailh_MX_1.00u
SW17: SW_tab; SW_Hotswap_Kailh_MX_1.50u
SW18: SW_q; SW_Hotswap_Kailh_MX_1.00u
SW19: SW_w; SW_Hotswap_Kailh_MX_1.00u
SW20: SW_e; SW_Hotswap_Kailh_MX_1.00u
SW21: SW_r; SW_Hotswap_Kailh_MX_1.00u
SW22: SW_t; SW_Hotswap_Kailh_MX_1.00u
SW23: SW_y; SW_Hotswap_Kailh_MX_1.00u
SW24: SW_u; SW_Hotswap_Kailh_MX_1.00u
SW25: SW_i; SW_Hotswap_Kailh_MX_1.00u
SW26: SW_o; SW_Hotswap_Kailh_MX_1.00u
SW27: SW_p; SW_Hotswap_Kailh_MX_1.00u
SW28: SW_[; SW_Hotswap_Kailh_MX_1.00u
SW29: SW_back; SW_Hotswap_Kailh_MX_2.00u
SW30: SW_del; SW_Hotswap_Kailh_MX_1.00u
SW31: SW_caps; SW_Hotswap_Kailh_MX_1.75u
SW32: SW_a; SW_Hotswap_Kailh_MX_1.00u
SW33: SW_s; SW_Hotswap_Kailh_MX_1.00u
SW34: SW_f; SW_Hotswap_Kailh_MX_1.00u
SW35: SW_g; SW_Hotswap_Kailh_MX_1.00u
SW36: SW_h; SW_Hotswap_Kailh_MX_1.00u
SW37: SW_j; SW_Hotswap_Kailh_MX_1.00u
SW38: SW_k; SW_Hotswap_Kailh_MX_1.00u
SW39: SW_l; SW_Hotswap_Kailh_MX_1.00u
SW40: SW_;; SW_Hotswap_Kailh_MX_1.00u
SW41: SW_'; SW_Hotswap_Kailh_MX_1.00u
SW42: SW_]; SW_Hotswap_Kailh_MX_1.00u
SW43: SW_ins; SW_Hotswap_Kailh_MX_1.00u
SW44: SW_shift; SW_Hotswap_Kailh_MX_2.25u
SW45: SW_z; SW_Hotswap_Kailh_MX_1.00u
SW46: SW_x; SW_Hotswap_Kailh_MX_1.00u
SW47: SW_v; SW_Hotswap_Kailh_MX_1.00u
SW48: SW_b; SW_Hotswap_Kailh_MX_1.00u
SW49: SW_n; SW_Hotswap_Kailh_MX_1.00u
SW50: SW_m; SW_Hotswap_Kailh_MX_1.00u
SW51: SW_,; SW_Hotswap_Kailh_MX_1.00u
SW52: SW_.; SW_Hotswap_Kailh_MX_1.00u
SW53: SW_/; SW_Hotswap_Kailh_MX_1.00u
SW54: SW_r_shift; SW_Hotswap_Kailh_MX_2.75u
SW55: SW_\; SW_Hotswap_Kailh_MX_1.50u
SW56: SW_c; SW_Hotswap_Kailh_MX_1.00u
SW57: SW_fn1; SW_Hotswap_Kailh_MX_1.00u
SW58: SW_ctrl; SW_Hotswap_Kailh_MX_1.25u
SW59: SW_super; SW_Hotswap_Kailh_MX_1.25u
SW60: SW_alt; SW_Hotswap_Kailh_MX_1.25u
SW61: SW_d; SW_Hotswap_Kailh_MX_1.00u
SW62: SW_space; SW_Hotswap_Kailh_MX_6.25u
SW63: SW_fn2; SW_Hotswap_Kailh_MX_1.00u
SW64: SW_left; SW_Hotswap_Kailh_MX_1.00u
SW65: SW_down; SW_Hotswap_Kailh_MX_1.00u
SW66: SW_up; SW_Hotswap_Kailh_MX_1.00u
SW67: SW_right; SW_Hotswap_Kailh_MX_1.00u
SW68: SW_enter; SW_Hotswap_Kailh_MX_2.25u

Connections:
C0: D1.2 (A), D8.1 (K); also elsewhere on the board
C1: D2.2 (A), D9.1 (K); also elsewhere on the board
C2: D3.2 (A), D10.1 (K); also elsewhere on the board
C3: D4.2 (A), D11.1 (K); also elsewhere on the board
C4: D5.2 (A), D12.1 (K); also elsewhere on the board
C5: D6.2 (A), D13.1 (K); also elsewhere on the board
C6: D7.2 (A), D14.1 (K); also elsewhere on the board
Encoder_SW_1: D15.2 (A); also elsewhere on the board
Encoder_SW_2: D1.1 (K), SW16.2 (B), SW30.2 (B), SW43.2 (B), SW57.2 (B); also elsewhere on the board
Extra1: D47.2 (A); also elsewhere on the board
Extra2: D61.2 (A); also elsewhere on the board
Extra3: D75.2 (A); also elsewhere on the board
ExtraSource: D5.1 (K), SW6.2 (B), SW20.2 (B); also elsewhere on the board
unnamed: D2.1 (K), SW3.2 (B), SW17.2 (B), SW31.2 (B), SW44.2 (B), SW58.2 (B)
unnamed: D3.1 (K), SW4.2 (B), SW18.2 (B), SW32.2 (B), SW45.2 (B), SW59.2 (B)
unnamed: D4.1 (K), SW5.2 (B), SW19.2 (B), SW33.2 (B), SW46.2 (B), SW60.2 (B)
unnamed: D6.1 (K), SW7.2 (B), SW21.2 (B), SW34.2 (B), SW47.2 (B), SW56.2 (B)
unnamed: D7.1 (K), SW8.2 (B), SW22.2 (B), SW35.2 (B), SW48.2 (B), SW61.2 (B)
unnamed: D8.2 (A), SW9.2 (B), SW23.2 (B), SW36.2 (B), SW49.2 (B), SW62.2 (B)
unnamed: D9.2 (A), SW10.2 (B), SW24.2 (B), SW37.2 (B), SW50.2 (B), SW63.2 (B)
unnamed: D10.2 (A), SW11.2 (B), SW25.2 (B), SW38.2 (B), SW51.2 (B), SW64.2 (B)
unnamed: D11.2 (A), SW12.2 (B), SW26.2 (B), SW39.2 (B), SW52.2 (B), SW65.2 (B)
unnamed: D12.2 (A), SW13.2 (B), SW27.2 (B), SW40.2 (B), SW53.2 (B), SW66.2 (B)
unnamed: D13.2 (A), SW14.2 (B), SW28.2 (B), SW41.2 (B), SW54.2 (B), SW67.2 (B)
unnamed: D14.2 (A), SW15.2 (B), SW29.2 (B), SW42.2 (B), SW55.2 (B), SW68.2 (B)
unnamed: D16.2 (A), SW3.1 (A)
unnamed: D17.2 (A), SW4.1 (A)
unnamed: D18.2 (A), SW5.1 (A)
unnamed: D19.2 (A), SW6.1 (A)
unnamed: D20.2 (A), SW7.1 (A)
unnamed: D21.2 (A), SW8.1 (A)
unnamed: D22.1 (K), SW9.1 (A)
unnamed: D23.1 (K), SW10.1 (A)
unnamed: D24.1 (K), SW11.1 (A)
unnamed: D25.1 (K), SW12.1 (A)
unnamed: D26.1 (K), SW13.1 (A)
unnamed: D27.1 (K), SW14.1 (A)
unnamed: D28.1 (K), SW15.1 (A)
unnamed: D29.2 (A), SW16.1 (A)
unnamed: D30.2 (A), SW17.1 (A)
unnamed: D31.2 (A), SW18.1 (A)
unnamed: D32.2 (A), SW19.1 (A)
unnamed: D33.2 (A), SW20.1 (A)
unnamed: D34.2 (A), SW21.1 (A)
unnamed: D35.2 (A), SW22.1 (A)
unnamed: D36.1 (K), SW23.1 (A)
unnamed: D37.1 (K), SW24.1 (A)
unnamed: D38.1 (K), SW25.1 (A)
unnamed: D39.1 (K), SW26.1 (A)
unnamed: D40.1 (K), SW27.1 (A)
unnamed: D41.1 (K), SW28.1 (A)
unnamed: D42.1 (K), SW29.1 (A)
unnamed: D43.2 (A), SW30.1 (A)
unnamed: D44.2 (A), SW31.1 (A)
unnamed: D45.2 (A), SW32.1 (A)
unnamed: D46.2 (A), SW33.1 (A)
unnamed: D48.2 (A), SW34.1 (A)
unnamed: D49.2 (A), SW35.1 (A)
unnamed: D50.1 (K), SW36.1 (A)
unnamed: D51.1 (K), SW37.1 (A)
unnamed: D52.1 (K), SW38.1 (A)
unnamed: D53.1 (K), SW39.1 (A)
unnamed: D54.1 (K), SW40.1 (A)
unnamed: D55.1 (K), SW41.1 (A)
unnamed: D56.1 (K), SW42.1 (A)
unnamed: D57.2 (A), SW43.1 (A)
unnamed: D58.2 (A), SW44.1 (A)
unnamed: D59.2 (A), SW45.1 (A)
unnamed: D60.2 (A), SW46.1 (A)
unnamed: D62.2 (A), SW47.1 (A)
unnamed: D63.2 (A), SW48.1 (A)
unnamed: D64.1 (K), SW49.1 (A)
unnamed: D65.1 (K), SW50.1 (A)
unnamed: D66.1 (K), SW51.1 (A)
unnamed: D67.1 (K), SW52.1 (A)
unnamed: D68.1 (K), SW53.1 (A)
unnamed: D69.1 (K), SW54.1 (A)
unnamed: D70.1 (K), SW55.1 (A)
unnamed: D71.2 (A), SW57.1 (A)
unnamed: D72.2 (A), SW58.1 (A)
unnamed: D73.2 (A), SW59.1 (A)
unnamed: D74.2 (A), SW60.1 (A)
unnamed: D77.2 (A), SW61.1 (A)
unnamed: D78.1 (K), SW62.1 (A)
unnamed: D79.1 (K), SW63.1 (A)
unnamed: D80.1 (K), SW64.1 (A)
unnamed: D81.1 (K), SW65.1 (A)
unnamed: D82.1 (K), SW66.1 (A)
unnamed: D83.1 (K), SW67.1 (A)
unnamed: D84.1 (K), SW68.1 (A)
R0: D15.1 (K), D16.1 (K), D17.1 (K), D18.1 (K), D19.1 (K), D20.1 (K), D21.1 (K), D22.2 (A), D23.2 (A), D24.2 (A), D25.2 (A), D26.2 (A), D27.2 (A), D28.2 (A); also elsewhere on the board
R1: D29.1 (K), D30.1 (K), D31.1 (K), D32.1 (K), D33.1 (K), D34.1 (K), D35.1 (K), D36.2 (A), D37.2 (A), D38.2 (A), D39.2 (A), D40.2 (A), D41.2 (A), D42.2 (A); also elsewhere on the board
R2: D43.1 (K), D44.1 (K), D45.1 (K), D46.1 (K), D47.1 (K), D48.1 (K), D49.1 (K), D50.2 (A), D51.2 (A), D52.2 (A), D53.2 (A), D54.2 (A), D55.2 (A), D56.2 (A); also elsewhere on the board
R3: D57.1 (K), D58.1 (K), D59.1 (K), D60.1 (K), D61.1 (K), D62.1 (K), D63.1 (K), D64.2 (A), D65.2 (A), D66.2 (A), D67.2 (A), D68.2 (A), D69.2 (A), D70.2 (A); also elsewhere on the board
R4: D71.1 (K), D72.1 (K), D73.1 (K), D74.1 (K), D75.1 (K), D76.1 (K), D77.1 (K), D78.2 (A), D79.2 (A), D80.2 (A), D81.2 (A), D82.2 (A), D83.2 (A), D84.2 (A); also elsewhere on the board

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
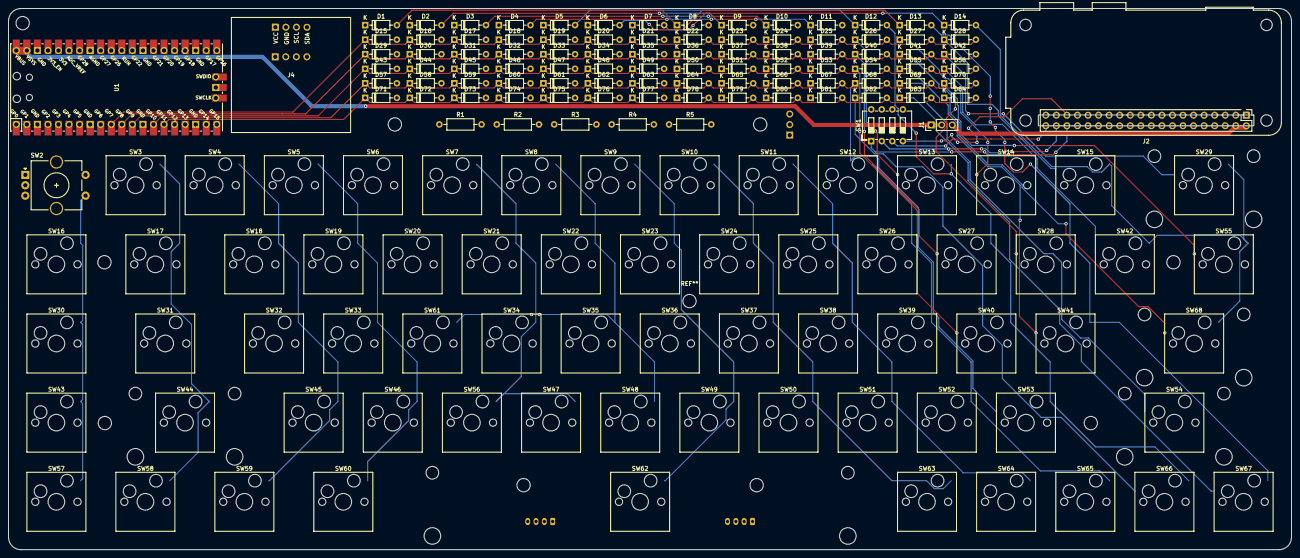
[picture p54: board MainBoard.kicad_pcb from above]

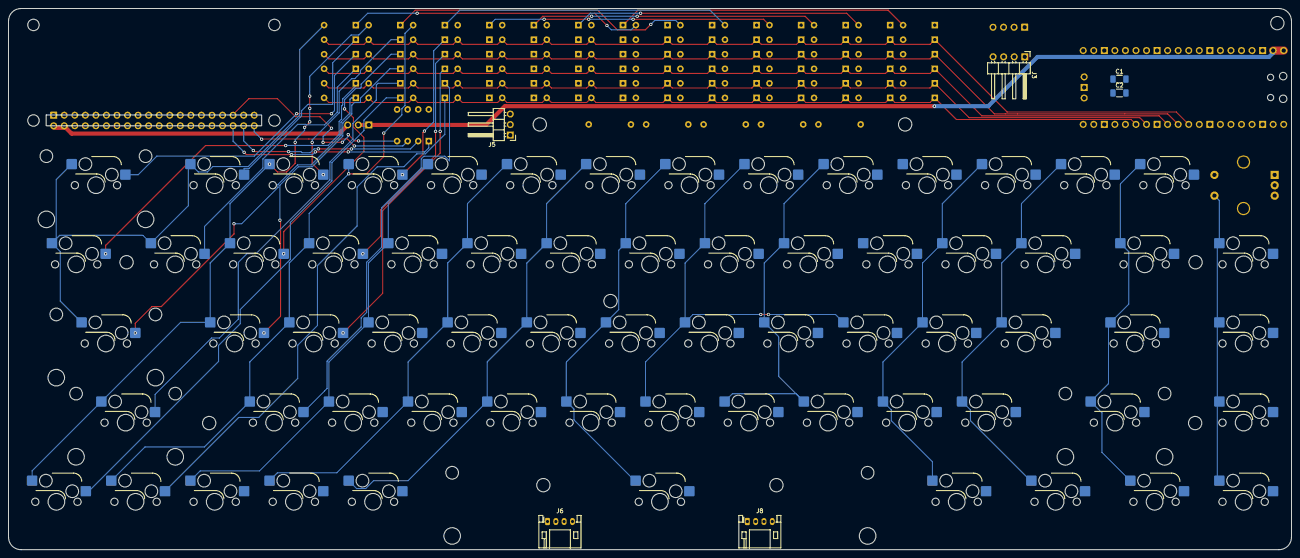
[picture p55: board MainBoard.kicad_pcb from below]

Board: 2 copper layers, 308.8 x 130.2 mm, 167 parts (6 on the bottom side), 117 nets.

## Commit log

2023-06-10 Added diodes for the duplex layout
    [MainBoard.kicad_pcb, MainBoard.kicad_sch, switch_matrix.kicad_sch]
2023-06-11 Updated 3d model
    [MainBoard.kicad_sch, switch_matrix.kicad_sch]
2023-06-11 Tentative layout
    [MainBoard.kicad_pcb]
2023-06-11 Layout settled
    [MainBoard.kicad_pcb, MainBoard.kicad_sch, switch_matrix.kicad_sch]
2023-06-11 Updated layout to add mounting holes
    [MainBoard.kicad_pcb, MainBoard.kicad_sch]
2023-06-11 Crazy wiring
    [MainBoard.kicad_pcb]
2023-06-14 Updated PCB
2023-06-14 Added gerber
    [MainBoard-NPTH-drl_map.gbr, MainBoard-NPTH.drl, MainBoard-PTH-drl_map.gbr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]
2023-06-15 Added silkscreen label
2023-06-18 Updated pcb a bit
2023-06-18 Custom diode footprint with proper silkscreen
    [switch_matrix.kicad_sch]
2023-06-18 Fixed solder mask around the mounting hole for pi
2023-06-23 Added pcb step file
2023-07-02 Added frame stl and dxf files
    [Bottom.dxf, BottomSpacer.stl, Plate.dxf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]
2023-07-03 Changed self tapping diameter
    [BottomSpacer.stl]
2023-07-03 Updated tapping hole diameter
    [BottomSpacer.stl]
2023-07-04 Fixed bottom plate hole
    [Bottom.dxf]
2023-07-08 Fixed the spacers, and added a thumb rest
    [Bottom.dxf, BottomSpacer.stl, BottomSpacerRing.stl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]
2023-07-21 Updated bottom dxf
    [Bottom.dxf]
2023-08-19 Updated bottom spacer
    [BottomSpacer.stl, BottomSpacerRing.stl, BottomSpacerRingThumbRest.stl]
2023-08-19 Updated plate dxf to have a rounded corner
    [Plate.dxf]
2023-08-19 Use switch instead of jumper
    [MainBoard.kicad_sch]
2023-08-20 Added instruction to install the driver
2023-09-04 Updated the bottom connector, and replotted the files
    [MainBoard-B_Cu.gbl, MainBoard-B_Mask.gbs, MainBoard-B_Paste.gbp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]
2023-09-04 Fixed pick and place center for switch footprint
    [switch_matrix.kicad_sch]
2023-09-04 Fixed silkscreen for the diodes
2023-09-04 Added SMT pads to the diodes
    [MainBoard.kicad_sch, switch_matrix.kicad_sch]
2023-09-04 Fixed silkscreen
2023-09-04 Added 0402 SMT capacitor
    [MainBoard.kicad_sch]
2023-09-05 Regenerate gerber
    [MainBoard-B_Cu.gbl, MainBoard-B_Cu.gbr, MainBoard-B_Mask.gbr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]
2023-09-06 Cleaned up a bit
    [MainBoard-B_Cu.gbl, MainBoard-B_Cu.gbr, MainBoard-B_Mask.gbr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]
2023-09-06 Changed the footprint and silkscreen
    [MainBoard.kicad_sch]
2023-09-09 Updated the diode silkscreen
2023-09-10 Updated the footprint of the pi zero
    [MainBoard.kicad_sch]
2023-09-13 Updated the bottom dxf
    [Bottom_New.dxf]
2023-09-21 Updated footprint
2023-09-21 Fixed trace being dangurously close to the border issue
2023-09-23 Removed some large files. Updated the laser cutting designs
    [Bottom.dxf, BottomSpacer.stl, BottomSpacerRing.stl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]
2023-09-24 Updated bottom plate
    [Bottom.dxf]
2023-09-24 Updated name for a switch
2023-09-24 Minor changes
    [MainBoard.kicad_sch, switch_matrix.kicad_sch]
2023-09-25 Small update to the traces
2023-09-25 Another small update to the traces
2023-09-28 Updates to the screw size
    [Bottom.dxf, Plate.dxf, TopBar.dxf]
2023-09-28 Updated a trace
2023-10-02 Moved traces further away from the edge
2023-10-07 Added gerber files
    [MainBoard-B_Cu.gbl, MainBoard-B_Cu.gbr, MainBoard-B_Mask.gbr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]
2023-10-09 Updated silkscreen
    [MainBoard-B_Cu.gbl, MainBoard-B_Mask.gbs, MainBoard-B_Paste.gbp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]
2023-10-13 Added copper cutout for the antenna
2023-11-19 Added frame assembly
